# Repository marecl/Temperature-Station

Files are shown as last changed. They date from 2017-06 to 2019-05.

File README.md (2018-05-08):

# Temperature Station  
## I made this project for my father who needed to log activity of central heater  

Please use PCF8563_JSON version.  
I2C expander is ATmega board which will extend amount of sensors that can be connected (WIP).  

If there is Error[500] use another browser (8563 donsent work with Edge but DS32321 does idk why)  
	
		!!!TODO!!!  

	Main sketch:  
		1. Add SSL support (including login page)  
		2. WWW based updater  
		3. Automatic daylight saving  
		4. Encrypt WiFi password   
		5. Set date and time on the webpage  
		6. Save each file as JSON and show as CSV  
		7. SettingsGenerator for everything but sensors

	Czas.h library:  
		1. Return actual date and time as epoch  

	Hardware:   
		1. Make full-SMD version (without NodeMCU, just ESP-12E)

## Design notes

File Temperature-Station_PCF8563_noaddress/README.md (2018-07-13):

# This version is getting all updates  

It's using single JSON (saved as text) file to store all settings.  

Warning: This is still under development.  
You will need to use LwIP 1.4 Higher Bandwidth to compile due to UDP problems.  
  
Features:  
	1. Single configuration file  
	2. (quite) Easy configuration 
	3. Stable

	SDfiles:  
		Copy index.htm to the root of SDcard.  
		
	SETTINGS.TXT:  
		*To Do*  
	
# Warning on first run! (workaround)   
If You need to get sensor addresses and You are generating settings for the first time:  
		1. Asked for name and address enter whatever you want    
		(write 000,000,000,000,000,000,000,000)
		2. Enter \quit.
		3. Configure network
			3.1. IP address will be saved to settings file  
		4. Connect to Your station [ip]/sensors   
		5. Remove 000,000(and so on) sensor and name sensors shown in table.  
		Checkbox checked - this sensor's name will be removed.  

SettingsGenerator has got validation mechanisms. They're working for me.  
When invalid address (sensor or IP) is entered it will ask you to write it again. Simple.  

Order of logged temperatures is just as order in file.  
If you change this file remember to rename your current log file.  
For logging changes will be applied immediately, but header will remain the same until new file is generated.

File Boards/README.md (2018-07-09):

Use legacy SDcard symbol from KiCad.
SDCARD.kicad_mod is footprint for PCB.

Created using KiCAD.

Mainboard_1.1 - early version. Obsolete.
Mainboard_2.0 - prototype. Never created.
Mainboard_3.0 - last version. Working.
RJ45_Breakout - early version of Muxtemp. Obsolete but working with Mainboard_3.0
Mainboard_Final - Muxtemp integrated into mainboard. To be tested.
Muxtemp - Muxtemp board. To be tested (probably will not due to limited resources)

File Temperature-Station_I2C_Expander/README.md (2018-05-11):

I2C expansion board for main devices.  

To add more devices change N_PORTS and fill _pins array with pins you'd like to use.

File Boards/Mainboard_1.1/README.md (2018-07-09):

First version.
Single sided.
Requires retracing some SD lines which were connected to GPIO9&10.
No i2c breakout.

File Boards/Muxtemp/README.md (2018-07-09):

Muxtemp board.

Default address is 0x10. If you don't like it - change it in sketch

!Lock - device is processing data (low state) or it's available (high)
1wire (jumpers closed) - master device will maintain 1wire circuit (Dosen't show specific port used)
1wire (jumpers open) - Muxtemp will maintain 1wire circuit like local sensors
SDA/SCL - I2C
3V3 - fused in case of short
3V3_L - Logic 3V3 (unfused)

Power supply header is used for external power regulator.

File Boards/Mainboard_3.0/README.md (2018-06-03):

Current version.
Dosent use NodeMCU (which was hard to set due to different board sizes and pins).
Two layers.
Prepared for external I2C devices (like more sensors or controllers).
Made to be compatible with ESP-12 breakout board.
Tested, 100% working.

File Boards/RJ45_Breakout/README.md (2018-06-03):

Breakout board with RJ45 sockets to connect various types of sensors.

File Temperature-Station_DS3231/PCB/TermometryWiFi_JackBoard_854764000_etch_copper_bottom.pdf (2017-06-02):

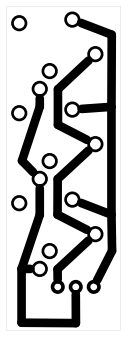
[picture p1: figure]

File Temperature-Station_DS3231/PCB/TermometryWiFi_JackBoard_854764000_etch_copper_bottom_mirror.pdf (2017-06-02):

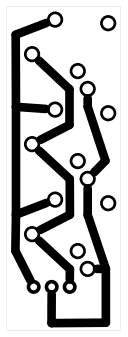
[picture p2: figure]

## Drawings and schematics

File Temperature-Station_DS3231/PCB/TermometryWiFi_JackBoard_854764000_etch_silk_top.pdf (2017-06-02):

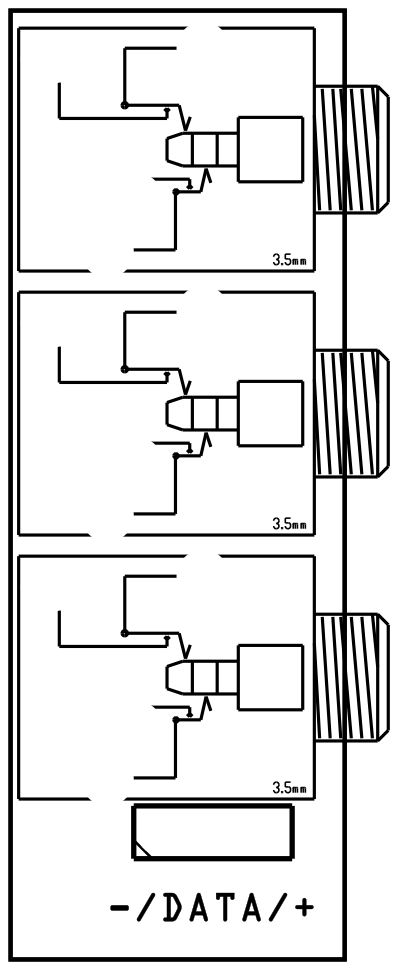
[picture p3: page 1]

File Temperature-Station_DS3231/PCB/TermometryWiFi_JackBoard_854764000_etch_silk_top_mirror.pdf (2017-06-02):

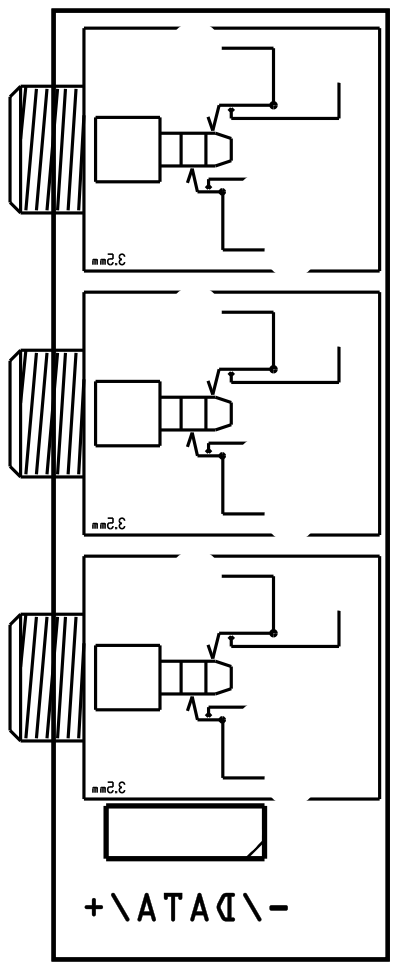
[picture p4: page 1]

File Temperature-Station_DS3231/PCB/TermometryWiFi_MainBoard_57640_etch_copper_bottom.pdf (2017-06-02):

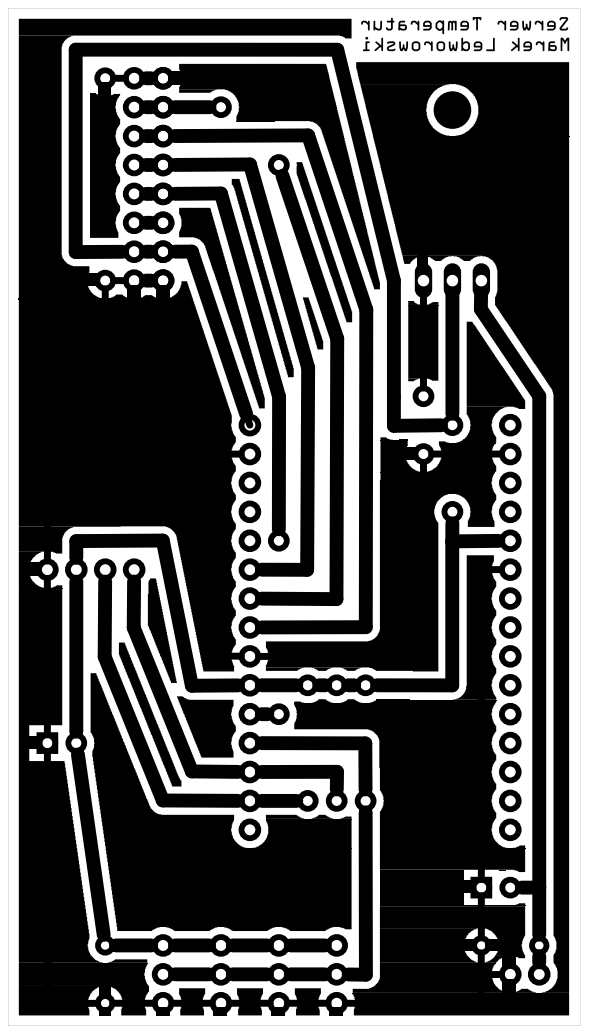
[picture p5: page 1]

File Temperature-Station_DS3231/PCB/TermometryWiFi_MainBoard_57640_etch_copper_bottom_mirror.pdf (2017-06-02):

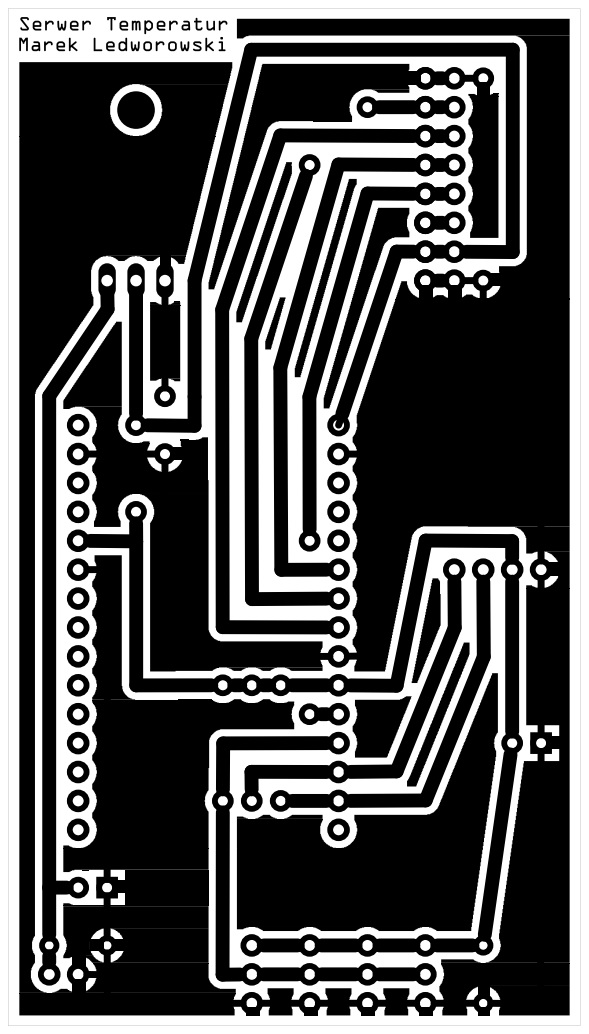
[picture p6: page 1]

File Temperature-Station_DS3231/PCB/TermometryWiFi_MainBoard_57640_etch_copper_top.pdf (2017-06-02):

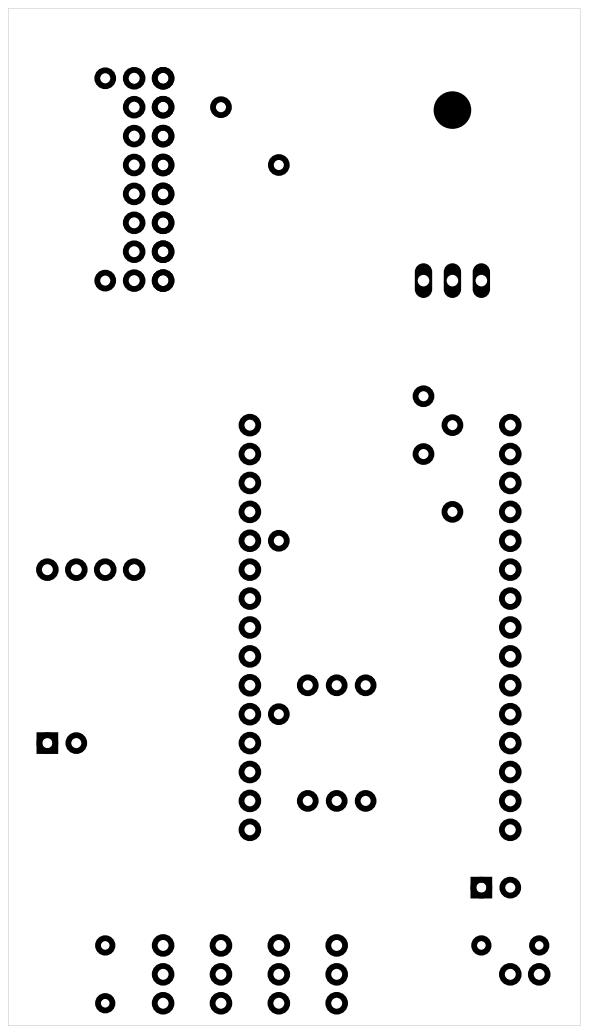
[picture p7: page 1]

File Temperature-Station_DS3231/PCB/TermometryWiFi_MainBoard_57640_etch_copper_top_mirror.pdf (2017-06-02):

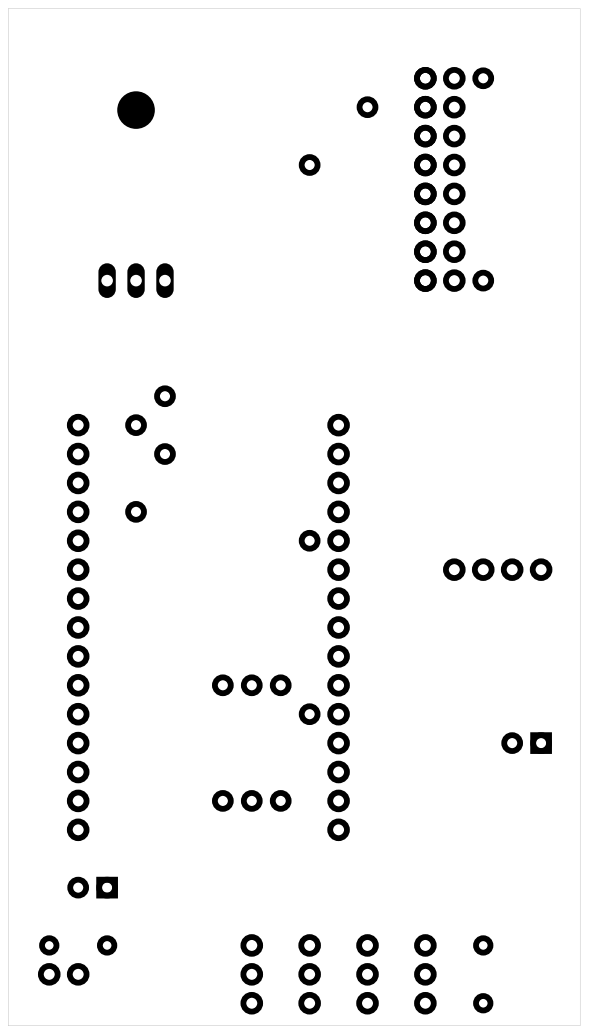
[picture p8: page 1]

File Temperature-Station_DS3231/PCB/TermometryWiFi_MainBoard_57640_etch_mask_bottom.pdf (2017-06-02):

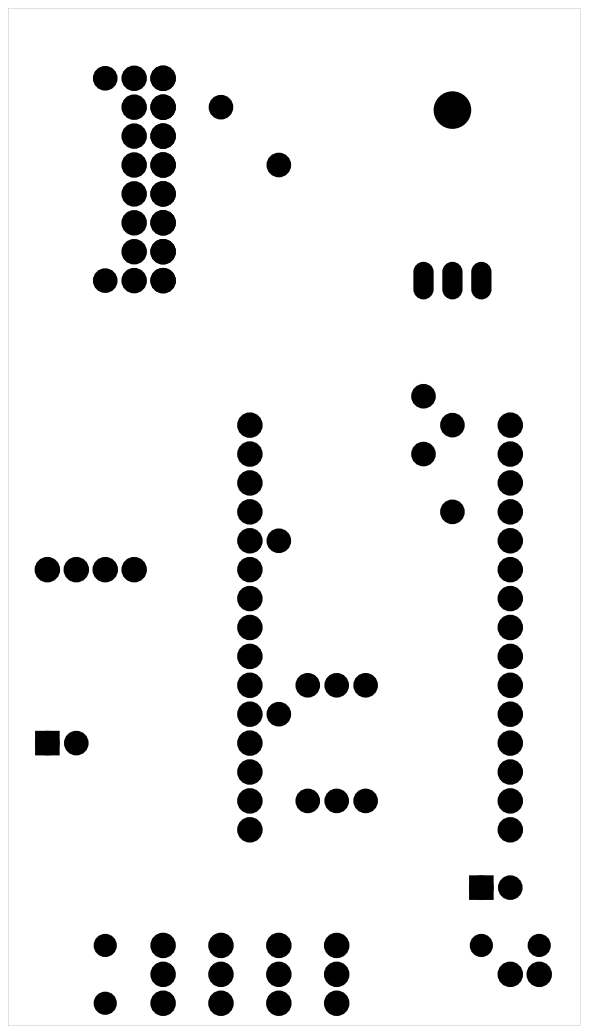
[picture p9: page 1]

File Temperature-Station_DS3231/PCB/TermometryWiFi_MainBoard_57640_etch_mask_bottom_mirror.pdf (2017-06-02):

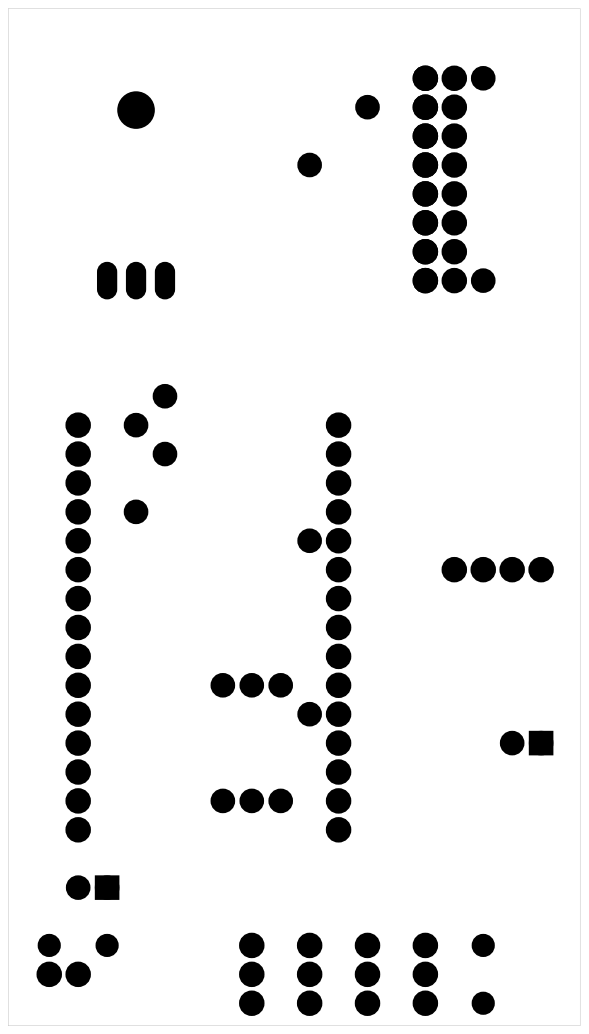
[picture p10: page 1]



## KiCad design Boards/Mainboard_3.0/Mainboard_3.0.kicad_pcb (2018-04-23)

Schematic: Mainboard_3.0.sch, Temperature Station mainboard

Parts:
BT1: Battery_Cell; BatteryHolder_Keystone_1058_1x2032
C1, C2, C3, C6, C7: 100nF; C_1206_3216Metric
C4, C5: 10uF; CP_EIA-6032-28_Kemet-C
D1, D2, D3: 1N4007; D_SMA
D4, D5: 1N4148; D_MiniMELF
J1: Breakout_Left; PinHeader_1x11_P2.54mm_Vertical
J2: Socket_Left; PinSocket_1x11_P2.54mm_Vertical_SMD_Pin1Left
J3: Jack-DC; BarrelJack_CUI_PJ-036AH-SMT_Horizontal
J4: Breakout_Right; PinHeader_1x11_P2.54mm_Vertical
J5: Socket_Right; PinSocket_1x11_P2.54mm_Vertical_SMD_Pin1Right
J6: 1-Wire; PinSocket_1x03_P2.54mm_Vertical_SMD_Pin1Left
J7: sensor_internal; PinSocket_1x03_P2.54mm_Vertical_SMD_Pin1Left
J8: Prog; PinHeader_1x05_P2.54mm_Horizontal
J9: SD_Card; SD_Card_Receptacle
J10: I2C Breakout; PinSocket_1x03_P2.54mm_Vertical_SMD_Pin1Left
Q1, Q2: S8050; TO-92
R1, R2, R3, R4, R5, R6, R7, R15: 4k7; R_1206_3216Metric
R8, R9, R10, R11, R12, R13, R14: 10k; R_1206_3216Metric
RJ1, RJ2, RJ3: 0; R_1206_3216Metric
U1: ESP-12E
U2: LM1117-3.3; SOT-223-3_TabPin2
U3: PCF8563T; SOIC-8_3.9x4.9mm_P1.27mm
Y1: 32,768kHz; Crystal_C26-LF_D2.1mm_L6.5mm_Horizontal_1EP_style1

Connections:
3v3: C2.1, C5.1, C6.1, C7.1, D3.2, D5.2, J2.8, J6.1, J7.1, J9.4, R2.1, R3.1, R4.1, R5.1, R6.1, R8.1, R9.1, R10.1, R11.1, R14.1, U2.2 (VO)
ADC: J2.2, J9.10, R14.2, R15.1
GND: BT1.2, C1.2, C2.2, C3.2, C4.2, C5.2, C6.2, C7.2, D1.2, J3.2, J3.3, J5.8, J6.3, J7.3, J8.5, J9.3, J9.6, J9.12, J9.13, J10.1, R1.1, R7.1, R15.2, U2.1 (GND), U3.4
GPIO0: J5.5, Q2.3, R5.2
GPIO2: J5.6, J6.2, J7.2, R6.2
GPIO4: J5.4, J10.3, R4.2, U3.6
GPIO5: J5.3, J10.2, R3.2, U3.5
GPIO12: J2.6, R8.2, RJ3.2
GPIO13: J2.7, J9.2, R10.2
GPIO14: J2.5, R9.2, RJ1.2
GPIO16: J2.4, J9.1, R11.2
unnamed: BT1.1, D4.2
unnamed: C3.1, C4.1, D2.1, D3.1, U2.3 (VI)
unnamed: D1.1, D2.2, J3.1
unnamed: D4.1, D5.1, U3.8
unnamed: J1.1, U1.11
unnamed: J1.2, U1.10
unnamed: J1.3, U1.9
unnamed: J1.4, U1.8
unnamed: J1.5, U1.7
unnamed: J1.6, U1.6
unnamed: J1.7, U1.5
unnamed: J1.8, U1.4
unnamed: J1.9, U1.3
unnamed: J1.10, U1.2
unnamed: J1.11, U1.1
unnamed: J2.3, R2.2
unnamed: J4.1, U1.12
unnamed: J4.2, U1.13
unnamed: J4.3, U1.14
unnamed: J4.4, U1.15
unnamed: J4.5, U1.16
unnamed: J4.6, U1.17
unnamed: J4.7, U1.18
unnamed: J4.8, U1.19
unnamed: J4.9, U1.20
unnamed: J4.10, U1.21
unnamed: J4.11, U1.22
unnamed: J5.7, R7.2
unnamed: J8.1, Q1.1, R13.2
unnamed: J8.2, Q2.1, R12.2
unnamed: J9.5, RJ1.1
unnamed: J9.7, RJ3.1
unnamed: Q1.2, R12.1
unnamed: Q1.3, RJ2.1
unnamed: Q2.2, R13.1
unnamed: U3.1, Y1.1
unnamed: U3.2, Y1.2
RST: C1.1, J2.1, R1.2, RJ2.2
RX: J5.2, J8.3
TX: J5.1, J8.4

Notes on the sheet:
ADC - SD_D GPIO12 - MISO GPIO13 - MOSI GPIO14 - SCK GPIO16 - CS GPIO2 - 1wire GPIO4 - SCL GPIO5 - SDA
GND TX -> RX RX -> TX RTS DTR

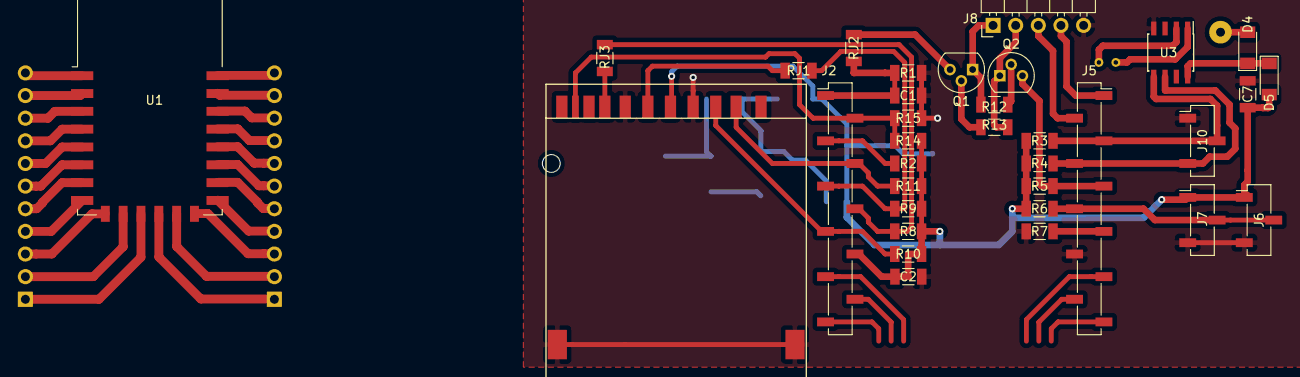
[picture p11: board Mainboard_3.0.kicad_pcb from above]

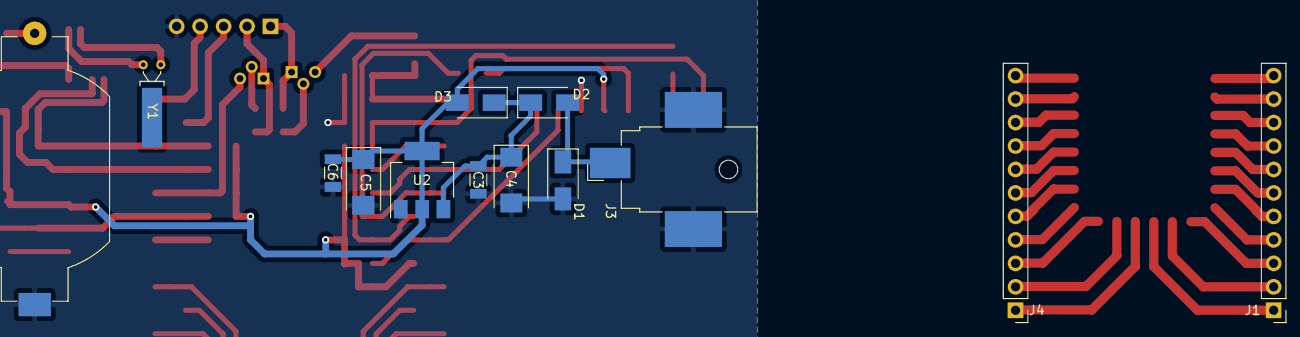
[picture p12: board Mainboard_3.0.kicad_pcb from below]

Board: 2 copper layers, 47 parts (13 on the bottom side), 51 nets.

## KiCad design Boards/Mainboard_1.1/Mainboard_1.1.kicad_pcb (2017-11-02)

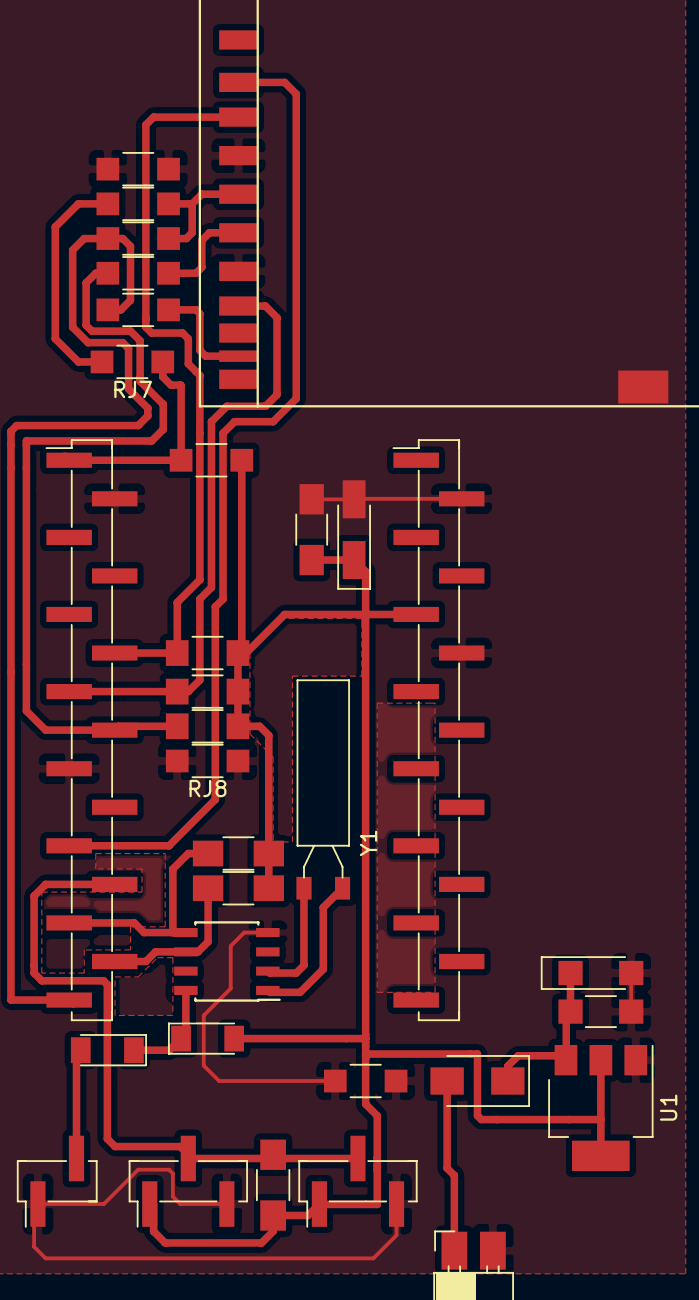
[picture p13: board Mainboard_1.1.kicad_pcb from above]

Board: 2 copper layers, 32 parts (0 on the bottom side), 18 nets.

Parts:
C1, C3: 10nF; C_1206_HandSoldering
C2, C4: 10uF; CP_Tantalum_Case-A_EIA-3216-18_Hand
D1, D3: 1N4148; D_MiniMELF
D2: 1N4007; D_SMA
J1, J5: CONN_01X03; Pin_Header_Straight_1x03_Pitch2.54mm_SMD_Pin1Left
J2, J3: CONN_01X15; Pin_Header_Straight_1x15_Pitch2.54mm_SMD_Pin1Left
J4: SD_Card; SDCARD-STANDARD
J6: CONN_01X02; Pin_Header_Straight_1x02_Pitch2.54mm_SMD_Pin1Left
J7: CONN_01X02; Socket_Strip_Angled_1x02_Pitch2.54mm
R1, R2, R3, R4: 10k; R_1206_HandSoldering
R5, R6, R7: 4k7; R_1206_HandSoldering
RJ1, RJ2, RJ3, RJ4, RJ5, RJ6, RJ7, RJ8: 0; R_1206_HandSoldering
U1: LM1117-3.3; SOT-223-3Lead_TabPin2
U2: PCF8563; SOIC-8_3.9x4.9mm_Pitch1.27mm
Y1: Crystal; Crystal_AT310_d3.0mm_l10.0mm_Horizontal

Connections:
1wire: J1.2, J2.12, J5.2, R5.2
3V3: C3.1, C4.1, D1.2, J1.1, J2.1, J3.5, J4.4, J5.1, R1.1, R2.1, R3.1, R4.1, R5.1, R6.1, R7.1, RJ2.1, RJ2.2, RJ3.1, RJ3.2, RJ7.1, RJ7.2, U1.2
CS: J2.11, J4.1
GND: C1.2, C2.2, C3.2, C4.2, J1.3, J2.2, J2.9, J3.2, J3.6, J4.3, J4.6, J4.12, J5.3, J6.1, J7.2, RJ4.1, RJ4.2, RJ6.1, RJ6.2, RJ8.1, RJ8.2, U1.1, U2.4
MISO: J2.7, J4.7, R2.2
MOSI: J2.6, J4.2, R1.2
unnamed: C1.1, C2.1, D2.1, U1.3
unnamed: D1.1, D3.1, U2.8
unnamed: D2.2, J7.1
unnamed: D3.2, J6.2
unnamed: J2.8, R3.2, RJ1.1
unnamed: J4.10, RJ5.2
unnamed: U2.1, Y1.1
unnamed: U2.2, Y1.2
SCK: J4.5, RJ1.2
SCL: J2.14, R7.2, U2.6
SDA: J2.13, R6.2, U2.5
SD_D: J2.15, R4.2, RJ5.1

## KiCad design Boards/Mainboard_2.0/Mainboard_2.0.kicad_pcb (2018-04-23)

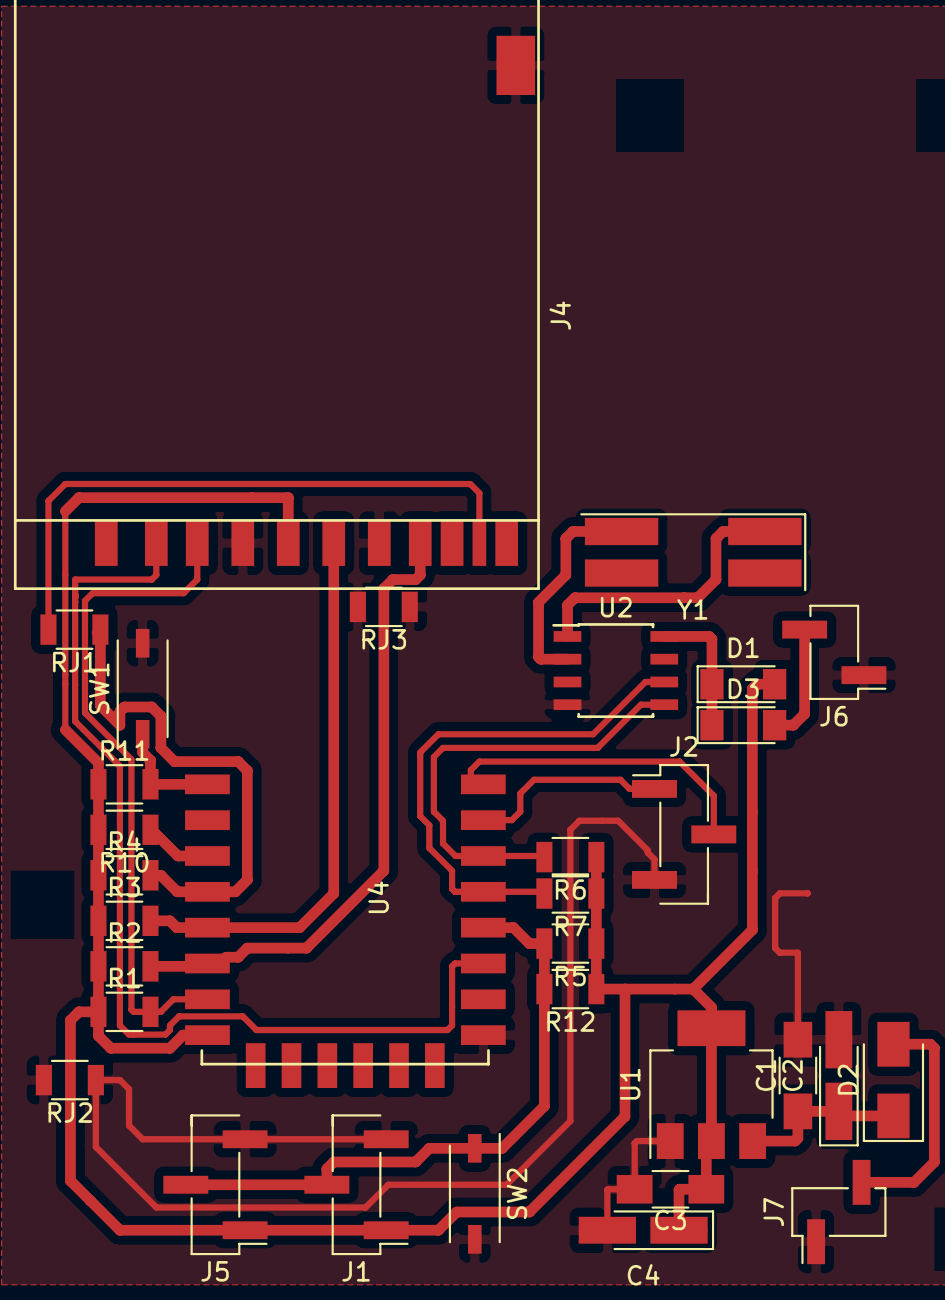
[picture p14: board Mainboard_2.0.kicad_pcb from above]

Board: 2 copper layers, 32 parts (0 on the bottom side), 21 nets.

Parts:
C1, C3: 10nF; C_1206_HandSoldering
C2, C4: 10uF; CP_Tantalum_Case-A_EIA-3216-18_Hand
D1, D3: 1N4148; D_MiniMELF
D2: 1N4007; D_SMA
J1, J2, J5: CONN_01X03; Pin_Header_Straight_1x03_Pitch2.54mm_SMD_Pin1Left
J4: SD_Card; SDCARD-STANDARD
J6, J7: CONN_01X02; Pin_Header_Straight_1x02_Pitch2.54mm_SMD_Pin1Left
R1, R2, R3, R4: 10k; R_1206
R5, R6, R7: 4k7; R_1206
R10, R11, R12: 1k; R_1206
RJ1, RJ2, RJ3: 0; R_1206
SW1: RESET; SW_DIP_x1_W5.08mm_Slide_Copal_CHS-A
SW2: FLASH; SW_DIP_x1_W5.08mm_Slide_Copal_CHS-A
U1: LM1117-3.3; SOT-223-3Lead_TabPin2
U2: PCF8563; SOIC-8_3.9x4.9mm_Pitch1.27mm
U4: ESP-12E; ESP-12E_SMD
Y1: Crystal; Crystal_SMD_SeikoEpson_MC406-4pin_9.6x4.1mm

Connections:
1wire: J1.2, J5.2, R5.2, R12.2, SW2.1, U4.12
3V3: C3.1, C4.1, D1.2, J1.1, J4.4, J5.1, R1.1, R2.1, R3.1, R4.1, R5.1, R6.1, R7.1, R10.2, R11.1, R12.1, U1.2, U4.8
CS: J4.1, U4.11
GND: C1.2, C2.2, C3.2, C4.2, J1.3, J2.3, J4.3, J4.6, J4.12, J5.3, J6.1, J7.1, RJ2.1, RJ2.2, RJ3.1, RJ3.2, SW1.2, SW2.2, U1.1, U2.4, U4.9
GPIO4: R7.2, U2.6, U4.13
GPIO5: R6.2, U2.5, U4.14
GPIO12: J4.7, R2.2, U4.6
GPIO13: J4.2, R1.2, U4.7
GPIO14: J4.5, R3.2, U4.5
unnamed: C1.1, C2.1, D2.1, U1.3
unnamed: D1.1, D3.1, U2.8
unnamed: D2.2, J7.2
unnamed: D3.2, J6.2
unnamed: J4.10, RJ1.2
unnamed: R10.1, U4.3
unnamed: U2.1, Y1.1
unnamed: U2.2, Y1.2
RESET: R11.2, SW1.1, U4.1
Rx: J2.1, U4.15
SD_D: R4.2, RJ1.1, U4.4
Tx: J2.2, U4.16

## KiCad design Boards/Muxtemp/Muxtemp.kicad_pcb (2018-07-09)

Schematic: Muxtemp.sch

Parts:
F1: 500mA; Fuse_1206_3216Metric
J1, J2, J3, J4, J5, J6, J7, J8: MHRJJ66NFRA; Manufacturer_Part_Number MHRJJ66NFRA
J9: ATmega Prog; PinHeader_1x04_P2.54mm_Vertical
J10: Conn; PinHeader_1x07_P2.54mm_Horizontal
J11: Power Supply; PinHeader_1x04_P2.54mm_Vertical
JP1, JP2, JP3, JP4, JP5, JP6, JP7, JP8, JP9: 1wireBypass; R_0612_1632Metric
R1, R2, R3, R4, R5, R6, R7, R8: 4k7; R_1206_3216Metric
R9, R10, R11, R12, R13, R14, R15, R16: 33k; R_1206_3216Metric
R17, R18: 100k; R_1206_3216Metric
R19: 10k; R_Axial_DIN0207_L6.3mm_D2.5mm_P10.16mm_Horizontal
U1: ATmega328P-AU; TQFP-32_7x7mm_P0.8mm

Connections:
1wire: J10.4, JP1.2, JP2.2, JP3.2, JP4.2, JP5.2, JP6.2, JP7.2, JP8.2, R17.2, U1.25 (PC2)
3V3: F1.1, J1.6, J2.6, J3.6, J4.6, J5.6, J6.6, J7.6, J8.6, R1.1, R2.1, R3.1, R4.1, R5.1, R6.1, R7.1, R8.1
3V3_L: F1.2, J10.6, J11.1, R19.1, U1.4 (VCC), U1.6 (VCC), U1.18 (AVCC)
GND: J1.2, J1.3, J2.2, J2.3, J3.2, J3.3, J4.2, J4.3, J5.2, J5.3, J6.2, J6.3, J7.2, J7.3, J8.2, J8.3, J9.1, J10.5, J11.2, JP9.2, R9.1, R10.1, R11.1, R12.1, R13.1, R14.1, R15.1, R16.1, R17.1, U1.3 (GND), U1.5 (GND), U1.21 (GND)
Lock: J10.3, U1.26 (PC3)
unnamed: J1.4, JP1.1
unnamed: J1.5, R1.2
unnamed: J2.4, JP2.1
unnamed: J2.5, R2.2
unnamed: J3.4, JP3.1
unnamed: J3.5, R3.2
unnamed: J4.4, JP4.1
unnamed: J4.5, R4.2
unnamed: J5.4, JP5.1
unnamed: J5.5, R5.2
unnamed: J6.4, JP6.1
unnamed: J6.5, R6.2
unnamed: J7.4, JP7.1
unnamed: J7.5, R7.2
unnamed: J8.4, JP8.1
unnamed: J8.5, R8.2
unnamed: J11.4, R18.1
unnamed: JP9.1, U1.24 (PC1)
unnamed: R19.2, U1.29 (~RESET~/PC6)
SCL: J10.1, U1.28 (PC5)
SDA: J10.2, U1.27 (PC4)
Vin: J10.7, J11.3, R18.2
dht_0: J1.1, J9.4, R9.2, U1.16 (PB4)
dht_1: J2.1, J9.3, R10.2, U1.15 (PB3)
dht_2: J3.1, J9.2, R11.2, U1.14 (PB2)
dht_3: J4.1, R12.2, U1.13 (PB1)
dht_4: J5.1, R13.2, U1.12 (PB0)
dht_5: J6.1, R14.2, U1.11 (PD7)
dht_6: J7.1, R15.2, U1.10 (PD6)
dht_7: J8.1, R16.2, U1.9 (PD5)

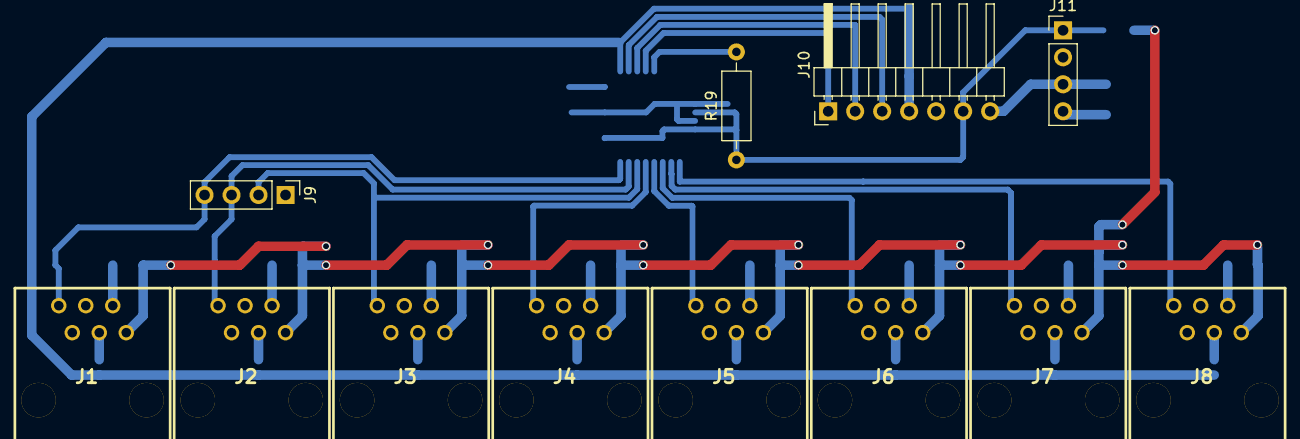
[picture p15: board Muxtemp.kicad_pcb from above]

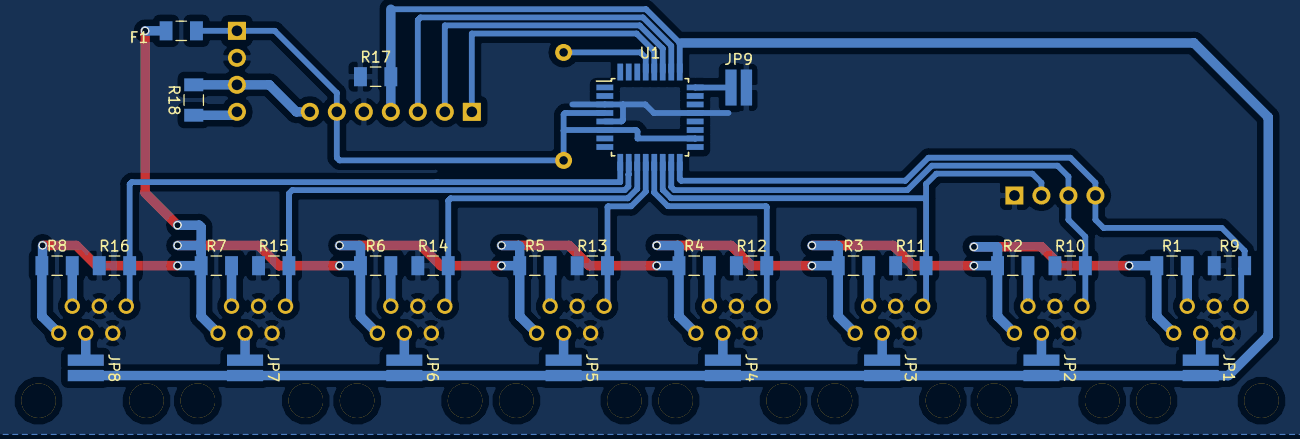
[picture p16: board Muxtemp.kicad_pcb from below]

Board: 2 copper layers, 41 parts (29 on the bottom side), 35 nets.

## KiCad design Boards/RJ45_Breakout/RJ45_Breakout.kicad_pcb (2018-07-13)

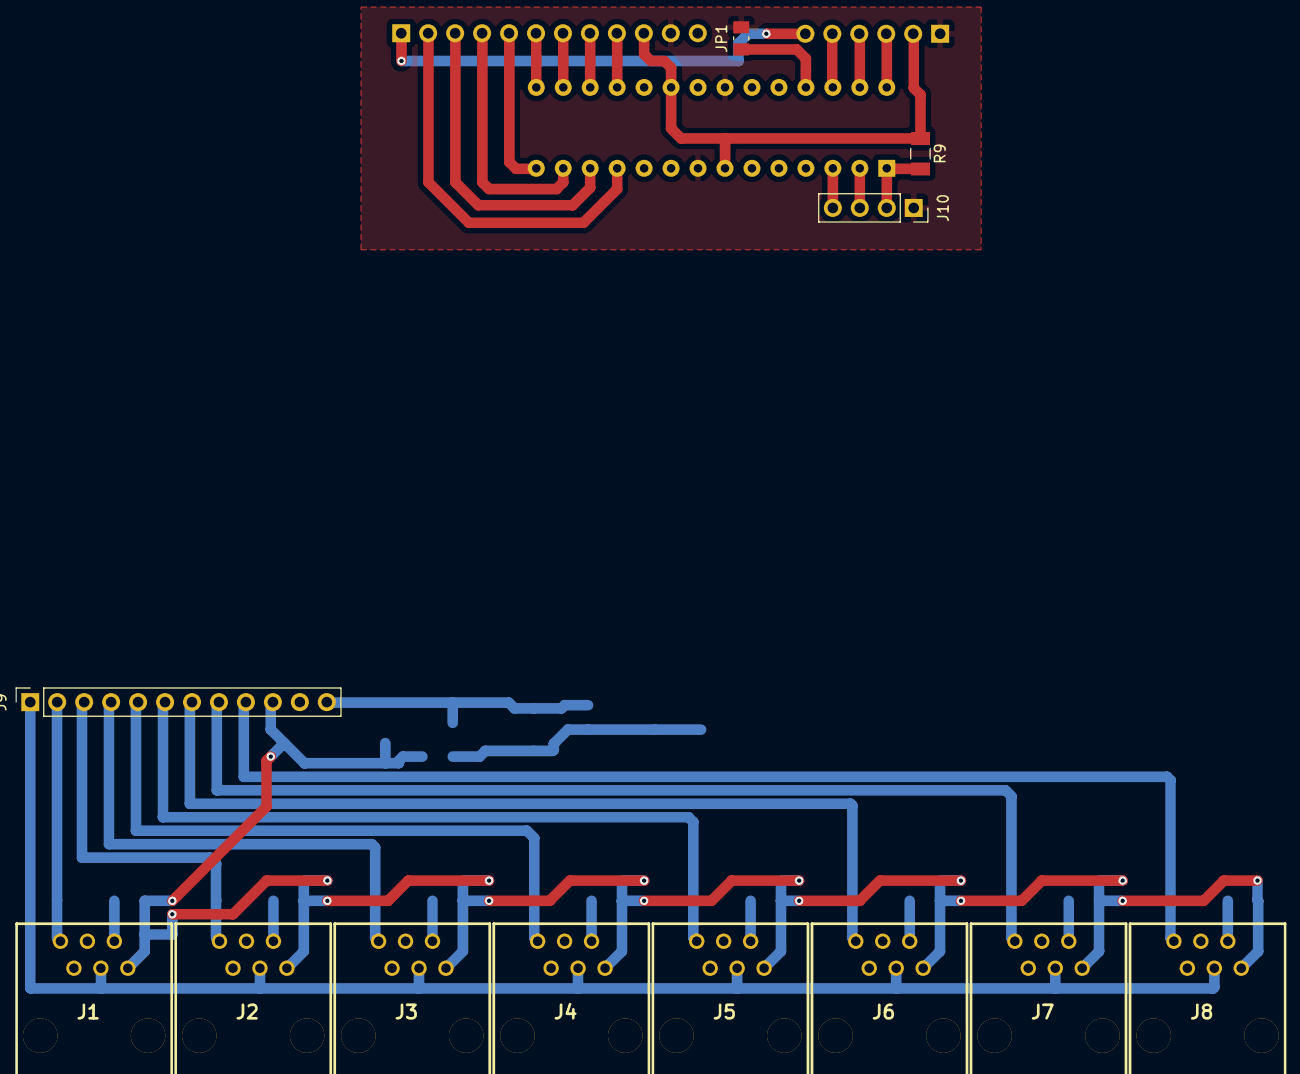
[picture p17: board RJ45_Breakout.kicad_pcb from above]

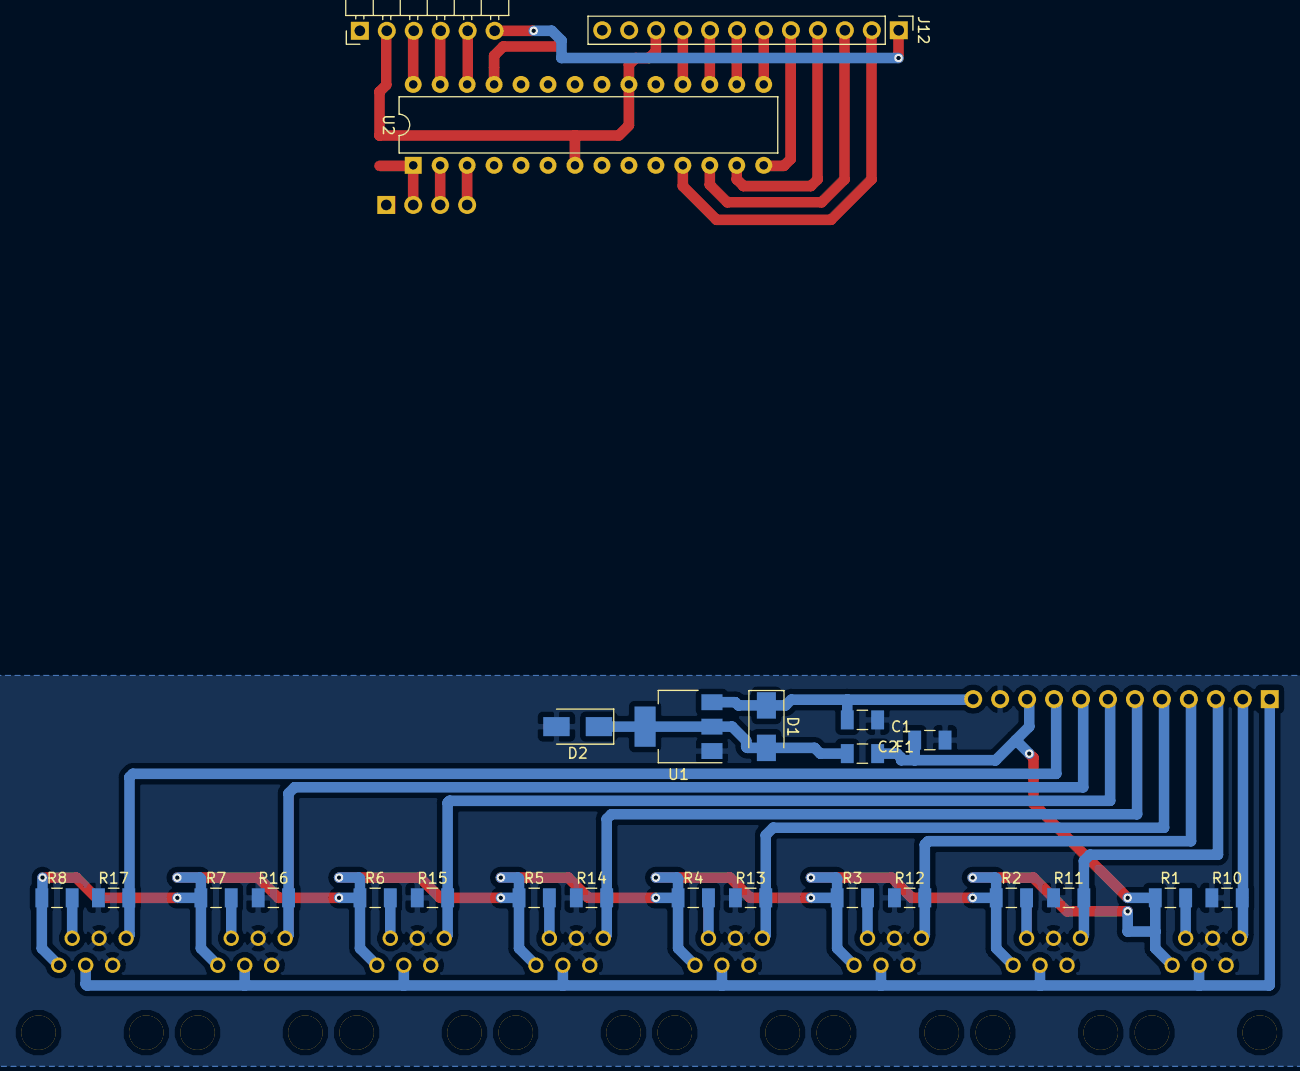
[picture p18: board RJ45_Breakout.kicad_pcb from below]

Board: 2 copper layers, 37 parts (25 on the bottom side), 28 nets.

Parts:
C1, C2: 100nF; C_1206_3216Metric
D1, D2: 1N4007; D_SMA
F1: 500mA; Fuse_1206_3216Metric
J1, J2, J3, J4, J5, J6, J7, J8: MHRJJ66NFRA
J9: Conn_01x12; PinSocket_1x12_P2.54mm_Vertical
J10: Prog; PinSocket_1x04_P2.54mm_Vertical
J11: Out; PinHeader_1x06_P2.54mm_Horizontal
J12: Flex; PinHeader_1x12_P2.54mm_Vertical
JP1: bypass1Wire; R_0805_2012Metric_Pad1.15x1.50mm_HandSolder
R1, R2, R3, R4, R5, R6, R7, R8: 4k7; R_1206_3216Metric
R9: 10k; R_1206_3216Metric
R10, R11, R12, R13, R14, R15, R16, R17: 33k; R_1206_3216Metric
U1: LM1117-3.3; SOT-223-3_TabPin2
U2: ATmega328-PU; DIP-28_W7.62mm

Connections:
1wire: J1.4, J2.4, J3.4, J4.4, J5.4, J6.4, J7.4, J8.4, J9.1, J11.6, J12.1
3V3: C2.1, F1.1, J1.6, J2.6, J3.6, J4.6, J5.6, J6.6, J7.6, J8.6, J9.10, J11.2, J12.10, R1.1, R2.1, R3.1, R4.1, R5.1, R6.1, R7.1, R8.1, R9.1, U2.7, U2.20
!Lock: J11.5, U2.26
GND: C1.2, C2.2, D2.2, J1.2, J1.3, J2.2, J2.3, J3.2, J3.3, J4.2, J4.3, J5.2, J5.3, J6.2, J6.3, J7.2, J7.3, J8.2, J8.3, J9.11, J10.1, J11.1, J12.11, JP1.2, R10.1, R11.1, R12.1, R13.1, R14.1, R15.1, R16.1, R17.1, U1.1, U2.8, U2.22
unnamed: D1.2, D2.1, F1.2, U1.2
unnamed: J1.5, R1.2
unnamed: J2.5, R2.2
unnamed: J3.5, R3.2
unnamed: J4.5, R4.2
unnamed: J5.5, R5.2
unnamed: J6.5, R6.2
unnamed: J7.5, R7.2
unnamed: J8.5, R8.2
unnamed: J10.2, R9.2, U2.1
unnamed: J10.3, U2.2
unnamed: J10.4, U2.3
unnamed: JP1.1, U2.25
SCL: J11.3, U2.28
SDA: J11.4, U2.27
Vin: C1.1, D1.1, J9.12, J12.12, U1.3
dht_0: J1.1, J9.2, J12.2, R10.2, U2.11
dht_1: J2.1, J9.3, J12.3, R11.2, U2.12
dht_2: J3.1, J9.4, J12.4, R12.2, U2.13
dht_3: J4.1, J9.5, J12.5, R13.2, U2.14
dht_4: J5.1, J9.6, J12.6, R14.2, U2.15
dht_5: J6.1, J9.7, J12.7, R15.2, U2.16
dht_6: J7.1, J9.8, J12.8, R16.2, U2.17
dht_7: J8.1, J9.9, J12.9, R17.2, U2.18

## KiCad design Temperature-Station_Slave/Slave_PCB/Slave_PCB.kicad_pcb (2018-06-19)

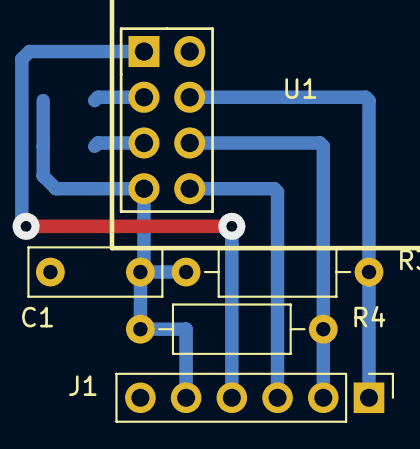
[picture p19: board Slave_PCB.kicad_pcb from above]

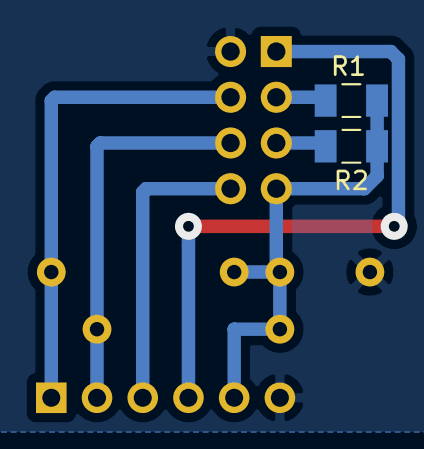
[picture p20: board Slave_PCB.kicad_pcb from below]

Board: 2 copper layers, 7 parts (2 on the bottom side), 8 nets.

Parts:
C1: 100nF; C_Rect_L7.2mm_W2.5mm_P5.00mm_FKS2_FKP2_MKS2_MKP2
J1: COM; PinHeader_1x06_P2.54mm_Vertical
R1, R2: 10k; R_1206_3216Metric
R3, R4: 4k7; R_Axial_DIN0207_L6.3mm_D2.5mm_P10.16mm_Horizontal
U1: ESP-01v090; ESP-01

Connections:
3V3: C1.1, J1.5, R1.1, R2.1, R3.2, R4.2, U1.7
GND: C1.2, J1.6, U1.2
unnamed: R1.2, U1.3
unnamed: R2.2, U1.5
SCL: J1.2, R4.1, U1.6
SDA: J1.1, R3.1, U1.4
hRX: J1.4, U1.1
hTX: J1.3, U1.8

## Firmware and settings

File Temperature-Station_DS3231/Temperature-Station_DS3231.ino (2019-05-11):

#include <ArduinoJson.h>
#include <ArduinoOTA.h>
#include <DallasTemperature.h>
#include <ESP8266HTTPUpdateServer.h>
#include <ESP8266WebServerSecure.h>
#include <ESP8266WiFi.h>
#include <OneWire.h>
#include <RtcDS3231.h>
#include <settingsManager.h>
#include <SD.h>
#include <SPI.h>
#include <Wire.h>
#include <WiFiUdp.h>
#include "CommonUtils.hpp"
#include "SensorsPageHandler.hpp"
#include "SensorsEditPageHandler.hpp"
#include "TimePageHandler.hpp"
#include "LoginPageHandler.hpp"

/*
   przy niewaznym ciasteczku przekierowac na /login
   naprawic /login
   Dostep do plikow przez strona/file=/[sciezka]
   wywalic strings.cpp
*/

#define FS_NO_GLOBALS
#include "FS.h"

/* Pin definitions */
#define SD_D D0     //GPIO16
#define SDA D1      //GPIO5
#define SCL D2      //GPIO4
#define OW_PORT D3  //GPIO0
#define SD_CS D4    //GPIO2

/* Good when trying different configurations */
#define SETTINGS_FILE "/SET.TXT" //SPIFFS
#define SENSORS_FILE "/DATA/SENSORS.TXT" //SD

/* Webpage */
extern char settings_htm[];

ESP8266WebServer server(80);
//ESP8266WebServerSecure server(443);
ESP8266HTTPUpdateServer updServer;

OneWire oneWire(OW_PORT);
DallasTemperature sensors(&oneWire);

RtcDS3231<TwoWire> zegar(Wire);
RtcDateTime teraz;

settingsManager settings(SETTINGS_FILE);

settingsManager* CommonUtils::setptr = &settings;
uint32_t CommonUtils::globalTimer = 0;

void setup() {
  SPIFFS.begin();
  WiFi.disconnect();
  WiFi.persistent(false);
  Serial.begin(115200);
  Serial.setDebugOutput(false);
  Serial.println(F("\r\n\r\nBooting..."));
  pinMode(SD_D, INPUT);

  if (!digitalRead(SD_D)) {
    if (SD.begin(SD_CS)) Serial.println(F("SD Card initialized"));
    else Serial.println(F("SD Card detected but cannot be initialized!"));
  } else Serial.println(F("No card inserted"));

#ifdef DEBUG_INSECURE
  settings.serialDebug(&Serial);
  //Use this section to overwrite settings while debugging
  settings.configSTA("", "");  // ssid and password
  settings.configAP("TemperatureStation");            // AP ssid
  settings.useDHCP(true);
  settings.name("TemperatureStation");                // Device name
  settings.ntpServer("tempus1.gum.gov.pl");           // NTP server (not pool)
  settings.configUser("admin", "admin");              // Login and password
  settings.timezone = 1;
  settings.useNTP = true;
  settings.readInterval = 10;                         // Read interval [min]
  settings.tokenLifespan = 600;                      // Cookie lifespan [s]
  settings.save();
  settings.printConfig();
#endif

  Serial.print(F("Loading..."));
  if (!settings.load()) { //Fill with default values
    Serial.println(F(" Fail"));
    settings.configUser("admin", "admin");
    settings.name(PSTR("TemperatureStation"));
    settings.configAP(("TemperatureStation" + (String)ESP.getChipId()).c_str(), "TemperatureStation");
  } else Serial.println(F("OK"));

  bool gotwifi = false;
  if (strcmp(settings.ssid(), "")) {
    Serial.print(F("Connecting to:\r\n\t"));
    Serial.print(settings.ssid());
    if (settings.beginSTA()) {
      Serial.print(F("\tSuccess \r\nIP Address:\t"));
      Serial.print(WiFi.localIP());
      gotwifi = true;
    } else {
      Serial.print(F("\tConnection failed"));
      gotwifi = false;
    }
    Serial.println();
  }

  if (!gotwifi) {
    Serial.print(F("Starting Access Point... "));
    Serial.println(settings.beginAP() ? F("Success") : F("Fail"));
    Serial.print(F("Connect to:\t"));
    Serial.println(settings.ssidAP());
  }

  sensors.begin();
  sensors.requestTemperatures();

  const char* headerkeys[] = {"Cookie"};
  uint16_t headerkeyssize = sizeof(headerkeys) / sizeof(char*);
  server.collectHeaders(headerkeys, headerkeyssize);
  //settings.configUpdateServer(&server, &updServer, "/update");
  //add SSL/BearSSL key
  server.addHandler(new LoginPageHandler("/login"));
  server.addHandler(new SensorsPageHandler("/sensors", &sensors, SENSORS_FILE));
  server.addHandler(new SensorsEditPageHandler("/editsaved", SENSORS_FILE));
  server.on("/settings", devconfig);
  //server.addHandler(new TimePageHandler("/time", &settings));
  server.on("/time", HTTP_POST, timeset);
  server.on("/logout", []() {
    server.sendHeader("Set-Cookie", settings.encryptKey(1));
    server.sendHeader("Location", "/login");
    server.sendHeader("Cache-Control", "no-cache");
    server.send(301);
  });
  server.onNotFound(handleNotFound);
  server.begin();
  settings.beginOTA();

  Serial.println(F("HTTP server:\tStarted"));

  if (!digitalRead(SDA))
    I2C_clearBus();

  Wire.begin(SDA, SCL);
  zegar.Begin();
  zegar.SetIsRunning(true);

  if (settings.useNTP) {
    teraz = zegar.GetDateTime();
    uint32_t newTime = updateNTP(settings.ntpServer());
    if ((newTime > 0 && (newTime - (uint32_t)teraz) > 59) || settings.lastUpdate == 0) {
      Serial.println(F("Adjusting time..."));
      Serial.println(PSTR("Before: ") + String(teraz));
      Serial.println(PSTR("Current: ") + String(newTime));
      zegar.SetIsRunning(false);
      zegar.SetDateTime(RtcDateTime(newTime));
      settings.lastUpdate = teraz;
      zegar.SetIsRunning(true);
    }
  }
  teraz = zegar.GetDateTime();
  char *date = new char[20];
  Serial.println(CommonUtils::printDateTime(date, &teraz));
  delete[] date;
  settings.save();

  CommonUtils::refreshSensors(&oneWire, SENSORS_FILE);

  DynamicJsonBuffer jsonBuffer(1000);
  File root = SD.open(SENSORS_FILE, FILE_READ);
  JsonArray& nSet = jsonBuffer.parseArray(root);
  root.close();

  Serial.println(F("\nLocal:"));
  uint8_t nSensor = nSet.size();
  for (uint8_t a = 0; a < nSensor; a++) {
    JsonArray& _e = nSet[a];
    Serial.print('\t' + String(a + 1) + "/" + String(nSensor) + ": ");
    Serial.print(_e[0].as<const char*>());
    if (CommonUtils::getTemp(&sensors, _e[1]) != -127)
      Serial.println(F(" Connected"));
    else Serial.println(F(" N/C"));
  }
}

void loop() {
  while (CommonUtils::globalTimer = zegar.GetDateTime(), \
         CommonUtils::globalTimer % (settings.readInterval * 60) != 0) {
    server.handleClient();
    ArduinoOTA.handle();
    yield();
  }

  if (!digitalRead(SD_D)) {
    sensors.requestTemperatures();
    teraz = zegar.GetDateTime();

    DynamicJsonBuffer jsonBuffer(1000);
    File root = SD.open(SENSORS_FILE , FILE_READ);
    JsonArray& nSet = jsonBuffer.parseArray(root);
    root.close();

    char* filename = new char[24];
    createFile(filename, 24, teraz);

    File dest = SD.open(filename, FILE_WRITE);

    char *date = new char[20];
    Serial.print(CommonUtils::printDateTime(date, &teraz));
    Serial.println(F("\tZapis"));

    dest.print(date);
    dest.print(F(";"));
    dest.print(settings.name());
    dest.print(F(":("));
    dest.flush();
    delete[] date;
    bool first = true;
    for (uint8_t c = 0; c < nSet.size(); c++) {
      JsonArray& _e = nSet[c];
      double tempRead = CommonUtils::getTemp(&sensors, _e[1]);
      if (tempRead == -127) continue;

      if (!first) dest.print(F(","));
      else first = false;
      dest.print(_e[0].as<const char*>());
      dest.print(F("="));
      dest.print(tempRead, 1);
      dest.flush();

    }
    dest.println(F(");"));
    dest.flush();
    dest.close();
    delete[] filename;
  } else {
    Serial.println(F("!!! NO SDCARD !!!"));
    while (digitalRead(SD_D)) {
      yield();
    }
    Serial.println(F("SD Card inserted. Rebooting..."));
    ESP.restart();
  }

  while (CommonUtils::globalTimer = zegar.GetDateTime(),
         CommonUtils::globalTimer % (settings.readInterval * 60) == 0) {
    server.handleClient();
    ArduinoOTA.handle();
    yield();
  }
}

uint32_t updateNTP(const char* ntpServerName) {
  WiFiUDP udp;
  IPAddress timeServerIP;
  udp.begin(2390);
  WiFi.hostByName(ntpServerName, timeServerIP);
  Serial.print(F("Time sync..."));

  byte packetBuffer[48];
  memset(packetBuffer, 0, 48);
  packetBuffer[0] = 0b11100011;
  packetBuffer[1] = 0;
  packetBuffer[2] = 6;
  packetBuffer[3] = 0xEC;
  packetBuffer[12] = 49;
  packetBuffer[13] = 0x4E;
  packetBuffer[14] = 49;
  packetBuffer[15] = 52;

  int cb = udp.parsePacket();

  uint8_t i = 0;
  while (!cb && i++ < 10) {
    udp.beginPacket(timeServerIP, 123);
    udp.write(packetBuffer, 48);
    udp.endPacket();
    udp.flush();
    delay(1000);
    cb = udp.parsePacket();
  }

  if (i < 10 && cb) {
    udp.read(packetBuffer, 48);
    unsigned long highWord = word(packetBuffer[40], packetBuffer[41]);
    unsigned long lowWord = word(packetBuffer[42], packetBuffer[43]);
    unsigned long secsSince1900 = highWord << 16 | lowWord;
    secsSince1900 -= 2208988800UL;
    secsSince1900 -= 946684800;
    secsSince1900 += settings.timezone * 3600;
    Serial.println(F(" OK"));
    return secsSince1900;
  }
  Serial.println(F(" Fail"));
  return false;
}

void devconfig() {
  if (!LoginPageHandler::verifyLogin(&server, &settings)) {
    LoginPageHandler::redirectToLogin(&server);
    return;
  }

  if (server.method() == HTTP_POST) {
    DynamicJsonBuffer output(JSON_OBJECT_SIZE(11));
    JsonObject& data = output.createObject();
    String resp;
    if (server.arg("a") == "l") {
      server.setContentLength(CONTENT_LENGTH_UNKNOWN);
      data["SN"] = settings.name();
      data["SS"] = settings.ssidAP();
      data["OS"] = settings.ssid();
      data["OI"] = settings.IPtoString(WiFi.localIP());
      data["OG"] = settings.IPtoString(WiFi.gatewayIP());
      data["OM"] = settings.IPtoString(WiFi.subnetMask());
      data["OD"] = settings.useDHCP();
      data["SL"] = settings.username();
      data["UN"] = settings.useNTP;
      data["NS"] = settings.ntpServer();
      data["TZ"] = settings.timezone;
      data.printTo(resp);
      server.send(200, F("application/json"), resp);
    } else if (server.arg("a") == "s") {
      if (server.hasArg("SS") && server.hasArg("SPA"))
        settings.configAP(server.arg("SS").c_str(),
                          server.arg("SPA").c_str());
      if (server.hasArg("OS") && server.hasArg("OP"))
        settings.configSTA(server.arg("OS").c_str(),
                           server.arg("OP").c_str());
      if (server.hasArg("OD"))
        settings.useDHCP(server.arg("OD")[0] == '1');
      if (server.hasArg("SN"))
        settings.name(server.arg("SN").c_str());
      if (server.hasArg("NL") && server.hasArg("NP"))
        settings.configUser(server.arg("NL").c_str(),
                            server.arg("NP").c_str());
      if (server.hasArg("OI"))
        settings.configIP(settings.stringToIP(server.arg("OI").c_str()),
                          settings.gatewayIP(),
                          settings.subnetMask());
      if (server.hasArg("OG"))
        settings.configIP(settings.localIP(),
                          settings.stringToIP(server.arg("OG").c_str()),
                          settings.subnetMask());
      if (server.hasArg("OM"))
        settings.configIP(settings.localIP(),
                          settings.gatewayIP(),
                          settings.stringToIP(server.arg("OM").c_str()));
      settings.save();
      CommonUtils::returnOK(&server, F("Settings saved"));
    } else if (server.arg("a") == "r") {
      CommonUtils::returnOK(&server, F("Settings reset. Rebooting..."));
      settings.remove(server.arg("SL").c_str(),
                      server.arg("SPL").c_str(),
                      SETTINGS_FILE);
      ESP.restart();
    } else CommonUtils::returnFail(&server, F("Method not allowed"));
  } else server.send(200, F("text/html"), settings_htm);
  return void();
}

void timeset() {
  if (!LoginPageHandler::verifyLogin(&server, &settings)) {
    LoginPageHandler::redirectToLogin(&server);
    return;
  }

  if (server.method() == HTTP_POST) {
    if (server.arg("a") == "l") {
      char _d[20];
      snprintf_P(_d, 20,
                 PSTR("%04u-%02u-%02uT%02u:%02u"),
                 teraz.Year(),
                 teraz.Month(),
                 teraz.Day(),
                 teraz.Hour(),
                 teraz.Minute());
      server.send(200, F("text/plain"), _d);
    } else if (settings.authenticate(
                 server.arg("SL").c_str(),
                 server.arg("SPL").c_str())) {
      if (server.arg("a") == "s") {
        if (server.hasArg("TZ"))
          settings.timezone = atoi(server.arg("TZ").c_str());
        if (server.hasArg("UN"))
          settings.useNTP = (server.arg("UN")[0] == '1');
        if (server.hasArg("NS"))
          settings.ntpServer(server.arg("NS").c_str());
        if (server.hasArg("EP")) {
          uint32_t newTime = strtoul(server.arg("EP").c_str(), NULL, 10);
          newTime += 3600 * settings.timezone;
          newTime -= 946684800;
          zegar.SetDateTime(RtcDateTime(newTime));
          settings.lastUpdate = newTime;
        }
        settings.save();
        returnOK(F("Time settings saved"));
      }
    } else CommonUtils::returnLoginFail(&server);
  }
  return void();
}

void returnOK(const __FlashStringHelper* _m) {
  server.send(200, F("text/plain"), _m);
  return void();
}

bool loadFromSdCard(String path) {
  if (digitalRead(SD_D))
    return false;
  String dataType = "text/plain";
  if (path.endsWith("/")) path += "index.htm";

  if (path.endsWith(".src")) path = path.substring(0, path.lastIndexOf("."));
  else if (path.endsWith(".htm")) dataType = "text/html";
  else if (path.endsWith(".csv")) dataType = "text/txt";

  File dataFile = SD.open(path.c_str(), FILE_READ);
  if (!dataFile)
    return false;

  if (server.streamFile(dataFile, dataType) != dataFile.size()) {
    Serial.println(F("Sent less data than expected!"));
  }

  dataFile.close();
  return true;
}

void handleNotFound() {
  if (!LoginPageHandler::verifyLogin(&server, &settings)) {
    LoginPageHandler::redirectToLogin(&server);
    return;
  }

  String p = server.uri();
  if (SD.exists("/data" + p) && !digitalRead(SD_D)) {
    handleIndex(p);
    return;
  }

  String message = F("PLIKU NIE ZNALEZIONO\n\n");
  message += F("URI: ");
  message += server.uri();
  message += F("\nMethod: ");
  message += (server.method() == HTTP_GET) ? F("GET") : F("POST");
  message += F("\nArguments: ");
  message += server.args();
  message += F("\n");
  for (uint8_t i = 0; i < server.args(); i++) {
    message += " NAME:" + server.argName(i) + "\n VALUE:" + server.arg(i) + "\n";
  }
  server.send(404, "text/plain", message);
}

void handleIndex(String path) {
  if (!LoginPageHandler::verifyLogin(&server, &settings)) {
    LoginPageHandler::redirectToLogin(&server);
    return;
  }

  File dir = SD.open("/data" + path, FILE_READ);
  if (!dir.isDirectory()) {
    dir.close();
    if (!digitalRead(SD_D) && loadFromSdCard("/data" + path)) return;
  }
  dir.rewindDirectory();

  server.setContentLength(CONTENT_LENGTH_UNKNOWN);
  server.sendContent(F("<!DOCTYPE html><html lang=\"en\">"));
  server.sendContent(F("<head><meta http-equiv=\"cache-control\" content"));
  server.sendContent(F("=\"no-cache\" /><title>Temperature Station"));
  server.sendContent(F("</title></head><body><a href=\"/logout\"><input type"));
  server.sendContent(F("=\"button\" value=\"Logout\" /></a><a href=\"/settings\">"));
  server.sendContent(F("<input type=\"button\" value=\"Settings\" /></a>"));
  server.sendContent(F("<a href=\"/sensors\"><input type=\"button\""));
  server.sendContent(F(" value=\"Sensors\" /></a><h1>Index of "));

  server.sendContent(path);
  server.sendContent(F("</h1><table><tr><th>Type</th><th>Name</th>"));
  server.sendContent(F("<th>Size</th></tr>"));

  server.sendContent(F("<tr><td>Dir</td><td><a href=\""));
  if (path.lastIndexOf('/') > 4)
    server.sendContent(path.substring(0, path.lastIndexOf('/')));
  else
    server.sendContent(F("/"));
  server.sendContent(F("\">..</a></td></tr>"));
  File entry;
  for (int cnt = 0; true; cnt++) {
    entry = dir.openNextFile();
    if (!entry) break;

    server.sendContent(F("<tr><td>"));
    server.sendContent(entry.isDirectory() ? F("Dir") : F("File"));
    server.sendContent(F("</td><td><a href=\""));
    server.sendContent(path);
    if (path != "/") server.sendContent("/");
    server.sendContent(String(entry.name()) + "\">");
    server.sendContent(entry.name());
    server.sendContent(F("</a></td><td>"));
    server.sendContent(String(entry.size()));
    server.sendContent(F("</td></tr>"));
  }
  entry.close();
  server.sendContent(F("</table></body></html>"));
  return void();
}

void createFile(char* _fn, uint8_t _buf, RtcDateTime& dt) {
  memset(_fn, 0, _buf);
  snprintf_P(_fn, _buf, PSTR("/data/%04u%02u"), dt.Year(), dt.Month());
  SD.mkdir(_fn);
  snprintf_P(_fn, _buf, PSTR("%s/%02u.csv"), _fn, dt.Day());
}

void I2C_clearBus() {
  //http://www.forward.com.au/pfod/ArduinoProgramming/I2C_ClearBus/index.html
  Serial.println(F("Resetting RTC I2C interface"));
  pinMode(SDA, INPUT_PULLUP);
  pinMode(SCL, INPUT_PULLUP);

  delay(2500);

  boolean SCL_LOW = (digitalRead(SCL) == LOW); // Check is SCL is Low.
  if (SCL_LOW)
    Serial.println("Cannot become master");

  boolean SDA_LOW = (digitalRead(SDA) == LOW);  // vi. Check SDA input.
  int clockCount = 20; // > 2x9 clock

  while (SDA_LOW && (clockCount > 0)) { //  vii. If SDA is Low,
    clockCount--;

    pinMode(SCL, INPUT);
    pinMode(SCL, OUTPUT);
    delayMicroseconds(10);
    pinMode(SCL, INPUT);
    pinMode(SCL, INPUT_PULLUP);
    delayMicroseconds(10); //  for >5uS
    // The >5uS is so that even the slowest I2C devices are handled.
    SCL_LOW = (digitalRead(SCL) == LOW); // Check if SCL is Low.
    int counter = 20;
    while (SCL_LOW && (counter > 0)) {  //  loop waiting for SCL to become High only wait 2sec.
      counter--;
      delay(100);
      SCL_LOW = (digitalRead(SCL) == LOW);
    }
    if (SCL_LOW) break;
    SDA_LOW = (digitalRead(SDA) == LOW); //   and check SDA input again and loop
  }
  if (SDA_LOW) { // still low
    Serial.println("SDA still low");
  }

  // else pull SDA line low for Start or Repeated Start
  pinMode(SDA, INPUT); // remove pullup.
  pinMode(SDA, OUTPUT);  // and then make it LOW i.e. send an I2C Start or Repeated start control.
  // When there is only one I2C master a Start or Repeat Start has the same function as a Stop and clears the bus.
  /// A Repeat Start is a Start occurring after a Start with no intervening Stop.
  delayMicroseconds(10); // wait >5uS
  pinMode(SDA, INPUT); // remove output low
  pinMode(SDA, INPUT_PULLUP); // and make SDA high i.e. send I2C STOP control.
  delayMicroseconds(10); // x. wait >5uS
  pinMode(SDA, INPUT); // and reset pins as tri-state inputs which is the default state on reset
  pinMode(SCL, INPUT);
  return void();
}

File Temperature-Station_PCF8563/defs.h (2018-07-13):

/*
  Mainboard_1.1
  #define SD_D D0 //GPIO16
  #define SDA D1 //GPIO5
  #define SCL D2 //GPIO4
  #define OW_PORT D3 //GPIO0
  #define SD_CS D4 //GPIO2
*/

#define SD_D A0
#define SDA 5
#define SCL 4
#define MUX_LOCK 2
#define SD_CS 16

//int isMember(byte, JsonArray&);
//int isMember(JsonArray&, JsonObject&);
//int isMember(int, JsonArray&);
int isMember(const uint8_t*, JsonArray&, uint8_t);
String addrToString(const uint8_t*, uint8_t);
//String addrToString(JsonArray&);

/*
   int isMember(byte _1[], JsonArray& compArr) {
  for (uint8_t a = 0; a < compArr.size(); a++) {
    for (uint8_t b = 0; b < 8; b++) {
      if (_1[b] != compArr[a][1][b].as<byte>())
        break;
      else if (b == 7) return a;
    }
  }
  return -1;
  }
*/

/*
  int isMember(JsonArray& locArr, JsonObject& remObj) {
  for (uint8_t locsiz = 0; locsiz < locArr.size(); locsiz++) {
    for (uint8_t a = 0; a < 8; a++) {
      if (locArr[locsiz][1][a].as<byte>() != remObj[1][a].as<byte>())
        break;
      else if (a == 7) return locsiz;
    }
  }
  return -1;
  }
*/

/*
  int isMember(int locAddr, JsonArray& remArr) {
  for (uint8_t remSiz = 0; remSiz < remArr.size(); remSiz++) {
    if (remArr[remSiz][1].is<int>() == false) continue;
    if (locAddr != remArr[remSiz][1].as<int>())
      continue;
    else return remSiz;
  }
  return -1;
  }
*/

int isMember(const uint8_t *_a, JsonArray& compArr, uint8_t _s) {
  for (uint8_t a = 0; a < compArr.size(); a++) {
    for (uint8_t b = 0; b < _s; b++) {
      if (*(_a + b) != compArr[a][1][b].as<uint8_t>())
        break;
      else if (b == 7) return a;
    }
  }
  return -1;
}

String addrToString(const uint8_t *_addr, uint8_t _s) {
  String out = "";
  for (uint8_t _a = 0; _a < _s; _a++)
    out += String(*(_addr + _a));
  return out;
}

/*
  String addrToString(JsonArray& _addr) {
  String out = "";
  for (uint8_t a = 0; (a < 8 && a < _addr.size()); a++)
    out += _addr[a].as<String>();
  return out;
  }
*/

void saveJson(JsonObject& toSave, const char* _f) {
  if (!toSave.success()) return;
  if (SD.exists(_f)) SD.remove(_f);
  File root = SD.open(_f, FILE_WRITE);
  toSave.printTo(root);
  root.flush();
  root.close();
  return void();
}

String printDateTime(Czas & timeobj) {
  char datestring[20];
  snprintf_P(datestring, 20,
             PSTR("%02u/%02u/%04u;%02u:%02u"),
             timeobj.day(),
             timeobj.month(),
             timeobj.year(),
             timeobj.hour(),
             timeobj.minute());
  return datestring;
}

void refreshSensors(Muxtemp* _s, const char* _n) {
  DynamicJsonBuffer jsonBuffer(2250);
  File root;
  if (!SD.exists(_n)) {
    Serial.println("no file yo");
    root = SD.open(_n, FILE_WRITE);
    root.print(F("{\"remote\":[],\"local\":[],\"saved\":[]}"));
    root.flush();
    root.close();
  }

  root = SD.open(_n);
  JsonObject& nSet = jsonBuffer.parseObject(root);
  root.close();

  JsonArray& _l = nSet["local"];
  JsonArray & _saved = nSet["saved"];

  bool _ch = false;
  int8_t dif = _s->getCount() - _l.size();
  if (dif > 0) {
    for (uint8_t z = 0; z < dif; z++) {
      JsonArray& _e = _l.createNestedArray();
      _e.add("Port_" + String(_l.size()));
      _e.add(false);
    }
    _ch = true;
  }

  _s->getPorts();
  for (int a = 0; a < _s->getCount(); a++) {
    JsonArray& _curr =  _l[a];
    uint8_t _type = _s->typeOf(a);
    switch (_type) {
      case 0: _curr[1] = false;
        _ch = true;
        break;
      case 11:
      case 21:
      case 22:
        _curr[1] = true;
        _ch = true;
        break;
      case 40:
        uint8_t *_q = _s->getAddress(a);
        int pos = isMember(_q, _saved, 8);
        if (pos == -1 && *_q == 40) {
          JsonArray& _new = _saved.createNestedArray();
          String _a = addrToString(_q, 8);
          _new.add(_a);
          JsonArray& _ad = _new.createNestedArray();
          for (uint8_t y = 0; y < 8; y++) _ad.add(*(_q + y));
          a--;
          break;
        } else _curr[1] = pos;
        delete _q;
        _ch = true;
        break;
    }
  }
  if (_ch) saveJson(nSet, _n);
  return;
}

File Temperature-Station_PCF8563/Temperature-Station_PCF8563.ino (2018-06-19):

#include <ArduinoJson.h> //github: bblanchon
#include <Czas.h> //PCF8563 library
#include <ESP8266HTTPUpdateServer.h>
//#include <ESP8266WebServer.h>
#include <ESP8266WebServerSecure.h>
#include <ESP8266WiFi.h>
#include <Muxtemp.h>
#include <Pinger.h> //Alessio Leoncini
#include <SD.h>
#include <SPI.h>
#include <WiFiClient.h>
#include <WiFiUdp.h>
#include "settingsHandler.h"
#include "html_set.h"

#define FS_NO_GLOBALS
#define DEFAULT_TIMEOUT 1000
#include "FS.h"
#include "defs.h"

/*
  curl -F "image=@Temperature-Station_PCF8563.ino.nodemcu.bin" -u admin:admin 192.168.2.98/update

  Pinger 1.0.0
  LwIP v2 Higher Bandwidth
  You need to generate x509 key using script somewhere in ESP examples
  When setting time - use GMT+0 time without DST  (DST will be automatic)

  ToDO:
    Remake /sensors button to sync 1wire with all devices
    Select if 1wire can override port name
    Select if master can overwrite slave settings
    Add backup options
    Automatic DST
    Secure connection with slave but dosen't need to be
    Move index to be hard-coded
    SET: require authentication, confirm password to change it or username
    Finish backend
    Encrypt passwords
*/
#define MAX_SENSORS 16

bool httpserver = false;
bool letni = true;
uint8_t ports = 0;
uint32_t nextAvailable = 0; //Solve this in Muxtemp only when scanning ports!
const uint32_t minDelay = 10000;

ESP8266WebServer server(80);
WiFiUDP udp;
//ESP8266WebServerSecure server(443);
ESP8266HTTPUpdateServer updServer;

WiFiClient telnet;
WiFiClient debugClient;
WiFiServer debugServer(23);

Czas zegar(Wire);
Muxtemp ext(Wire);
settingsHandler settings;

void setup() {
  pinMode(SD_D, INPUT);
  pinMode(0, OUTPUT);
  digitalWrite(2, LOW);

  //For testing purposes
  //ESP.eraseConfig();
  //SPIFFS.format();

  delay(1000);
  Wire.begin(SDA, SCL);
  Serial.begin(115200);
  Serial.println(F("Temperature Station"));
  Serial.setDebugOutput(false);
  WiFi.persistent(false);

  ///////////////////////////////
  IPAddress ip(192, 168, 2, 98);
  IPAddress gateway(192, 168, 2, 1);
  IPAddress subnet(255, 255, 255, 0);
  settings.configAP("TemperatureStation", "TemperatureStation");
  settings.useDHCP(false);
  settings.name("TemperatureStation");
  settings.configIP(ip, gateway, subnet);
  settings.ntpServer("tempus1.gum.gov.pl");
  settings.configUser("admin", "admin");
  settings.timezone = 1;
  settings.useNTP = true;
  Serial.println("Saving");
  settings.save("/set.txt");
  ///////////////////////////////

  Serial.print(F("Loading... "));
  settings.serialDebug(&Serial);
  if (!settings.load("/set.txt")) { //Defaults
    Serial.println(F("Fail"));
    settings.configUser("admin", "admin");
    settings.name("TemperatureStation");
    settings.configAP(("TemperatureStation" + (String)ESP.getChipId()).c_str(), "TemperatureStation");
  } else Serial.println(F("OK"));

  bool gotwifi = false;
  if (strcmp(settings.ssid(), "") != 0) {
    Serial.print(F("Connecting to:\r\n\t\t"));
    Serial.print(settings.ssid());
    Serial.print(F("... "));
    if (settings.beginWiFi()) {
      Serial.print(F("Success ("));
      Serial.print(WiFi.localIP());
      Serial.println(F(")"));
      gotwifi = true;
    } else {
      Serial.println(F("Connection failed"));
      gotwifi = false;
    }
  }
  if (!gotwifi) {
    Serial.println(F("Starting Access Point..."));
    settings.beginAP();
    Serial.print(F("Connect to:\t"));
    Serial.println(settings.ssidAP());
  }
  Serial.print(F("\r\nMuxtemp:\t"));
  Serial.println((ext.begin(0x10) == 0) ? F("Present") : F("Error"));
  Serial.print(F("Ports:  \t"));
  Serial.println(ext.getCount());
  Serial.print(F("1wire bypass:\t"));
  Serial.println(ext.bypass1Wire() ? F("yes") : F("no"));
  Serial.println();
  ext.refreshPorts();
  nextAvailable = millis() + minDelay;

  if (analogRead(SD_D) < 512) {
    if (SD.begin(SD_CS)) {
      Serial.println(F("SD Card initialized"));
      if (!SD.exists("/SENSORS.TXT"))
        Serial.println(F("No sensors file!"));
    } else Serial.println(F("SD Card detected but cannot be initialized!"));
  } else Serial.print(F("No card inserted\n"));

  settings.configUpdateServer(&server, &updServer, "/update");
  //server.setServerKeyAndCert_P(rsakey, sizeof(rsakey), x509, sizeof(x509));
  server.on("/settings", devconfig);
  server.on("/sensors", sensorSettings);
  server.on("/sensorsbdc", sensorBroadcast);
  server.on("/time", HTTP_POST, timeset);
  server.on("/list", HTTP_GET, printDirectory);
  server.on("/sysinfo", HTTP_GET, httpinfo);
  server.on("/", HTTP_DELETE, handleDelete);
  server.on("/", HTTP_PUT, handleCreate);
  server.on("/", HTTP_POST, []() {
    returnOK();
  }, handleFileUpload);
  server.onNotFound(handleNotFound);
  server.begin();
  Serial.println(F("HTTP server:\tStarted"));
  debugServer.begin();
  //This has no sense
  //But still it looks good while booting :)

  //Emergency connection - update or something
  //In case when dosen't detect SDcard, wrong config etc

  udp.begin(2390);
  zegar.readRTC();
  if (settings.useNTP && gotwifi) {
    Serial.print(F("NTP server:\t"));
    Serial.println(settings.ntpServer());
    uint32_t newTime = updateNTP(settings.ntpServer());
    Serial.print(F("NTP Time:\t"));
    Serial.println(newTime);
    Serial.print(F("Current Time:\t"));
    Serial.println(zegar.dateAsEpoch());
    if (newTime != 0 && ((newTime - zegar.dateAsEpoch()) > 59)) {
      Serial.println(F("Adjusting time..."));
      zegar.setRTC(newTime);
      delay(10);
      zegar.readRTC();
      settings.lastUpdate = newTime;
    }
    settings.save("/set.txt");
  }
  if (zegar.dateAsEpoch() < 59) zegar.setRTC(settings.lastUpdate);
  Serial.println(printDateTime(zegar));

  while (millis() < (nextAvailable - 5000))
    server.handleClient();

  refreshSensors(&ext, "/SENSORS.TXT");
  nextAvailable = millis() + minDelay;

  DynamicJsonBuffer jsonBuffer(2250);
  File root = SD.open("/SENSORS.TXT", FILE_READ);
  JsonObject& nSet = jsonBuffer.parseObject(root);
  root.close();

  JsonArray& _saved = nSet["saved"];
  Serial.println(F("\r\nLocal:"));
  for (int a = 0; a < ext.getCount(); a++) {
    uint8_t _type = ext.typeOf(a);
    JsonObject& _curr = nSet["local"][a];

    Serial.print('\t' + (String)(a + 1) + "/" + (String)(ext.getCount()) + ": ");
    Serial.print('\t' + String(ext.typeOf(a)) + '\t');
    if (_type == 0) Serial.print(F("N/C"));
    else if (_type != 5) {
      Serial.println(_curr["n"].as<const char*>());
      continue;
    } else if (_type == 5) {
      uint8_t *_q = ext.getAddress(a);
      int pos = isMember(_q, _saved, 8);
      Serial.print(_saved[pos]["n"].as<const char*>());
      Serial.print(F("\t("));

      for (uint8_t y = 0; y < 8; y++) {
        Serial.print(*(_q + y));
        if (y < 7) Serial.print(",");
        else Serial.print(')');
      }
    }
    Serial.println();
  }
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

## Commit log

2017-06-02 Initial commit
    Lots of things done, more to do.
    Works fine unless you want to use advanced options.
    Documentation planned in the future.
    [Mainboard_1.1.kicad_pcb, Mainboard_1.1.sch, Temperature-Station.fzz]
2017-06-03 Fixes
    Added static/dhcp option for obtaining IP address
    Little changes to code
    [Mainboard_1.1.kicad_pcb, Mainboard_1.1.sch]
2017-06-06 Fixes
    Fixed editing, saving and uploading documents to server
    Minor code changes
    Minor board changes
    [Mainboard_1.1.kicad_pcb]
2017-06-17 Mainboard changes
    [Mainboard_1.1.kicad_pcb, Mainboard_1.1.sch]
2017-06-18 templates
    Fixed template
    TODO: get temperature from device using table row number (order defined
    in template.txt)
2017-06-19 Things got better
    Added templates
    Improved method of logging
    Minor changes in board
    [Mainboard_1.1.kicad_pcb]
2017-06-20 Some things fixed
    Removed test sketches
    Working on JSON as config
    Some bugs fixed
    Modified IPconfig sketch to take ssid and pass from compiled sketch, not
    file on SDcard so it's easier to use.
    [Temperature-Station_PCF8563_JSON.ino, defs.h]
2017-06-21 JSON support added
    Now PCF8563 version is working with JSON configs. Less files, but
    responsibility is great.
    Works well as far, but the goal is removing vars containing addresses,
    sensor names and reading JSON directly from SDcard.
2017-06-26 Fixes
    Fixed opening files from archive file tree
    Idk HOW IT WAS CREATING NEW FILES before. Now everything is 100% legit.
    Still many things to do.
    [Temperature-Station_PCF8563_JSON.ino]
2017-06-27 Application, configuration
    See changes in README
    Added program to create settings.txt
    Added GET url (/sensors) to list all connected sensors (WIP)
    I forgot what else.
2017-07-01 Fixes and additions
    Splitted README files
    Modified SettingsGenerator
    Added "backup access points" feature on boot
    Fixed midnight bug
    [Mainboard1.1_LF33CDT.kicad_pcb, Mainboard1.1_LF33CDT.sch, Mainboard1.1_LM1117.kicad_pcb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]
2017-07-03 SettingsGenerator update
    Added validating addresses in SettingsGenerator
    Modified LM1117 board (SOT instead of DPAK voltage stabiliser)
    Something I forgot
    [Mainboard1.1_LM1117.kicad_pcb, Mainboard1.1_LM1117.sch]
2017-07-08 PCB work
    Started working on full SMD version. Update KiCAD library before opening
    this one.
    Modified code and moved clock settings to JSON (needs update!) - I must
    upload new JSON and SettingsGenerator.
    Set all strings to flash memory
    [Mainboard2.0_LM1117.kicad_pcb, Mainboard2.0_LM1117.sch]
2017-07-09 PCB work
    Need to remove 1.1 files from 2.0 folder
    Fixed component enumeration so PCB rework will be easier
    Still need to finish new PCB
    [Mainboard1.1_LM1117.sch, Mainboard2.0_LM1117.kicad_pcb, Mainboard2.0_LM1117.sch]
2017-07-15 Minor code changes
    Little cleanup
    Cosmetic changes
    Added keywords for Czas.h library and moved to it's own directory (otherwise keywords won't work)
    Removed unnescesary crap I forgot to remove earlier
    Updated description in README for PCF8563_JSON
    Updated SettingsGenerator for newest JSON
    Had a little fun with new PCB but I don't think it's gonna work out
    [Mainboard2.0_LM1117.kicad_pcb]
2017-07-16 Updates
    Added new IP obtain mode
    Changed PC program name
    Fixed compilator warnings
    Removed support for DHCP.txt file
    Czas.h: added function to compare given epoch to current date and time
    [Czas.cpp, Temperature-Station_PCF8563_JSON.ino, defs.h]
2017-07-25 SMD board complete
    Full SMD board is complete - needs to be tested though. Looks kinda awful, large SD card slot is taking lots of space.
    [Mainboard1.1_LM1117.sch, Mainboard2.0_LM1117.kicad_pcb, Mainboard2.0_LM1117.sch]
2017-09-20 Updates
    Ported DS3231 to JSON
    [Mainboard2.0_LM1117.kicad_pcb, Mainboard2.0_LM1117.sch]
2017-10-02 DS3231 update
    Change sensor names through /sensors
2017-10-04 DS3231 update
    Auto adding sensors
    Can remove unplugged sensors
    Auto-add freshly connected
    TODO:
    Fix removing sensors
    [defs.h]
2017-10-05 PCF8563&DS3231 Update
    Both versions have the same features (and bugs)
    Reworked NTP time setting
    Fixed sensor removing (kind of)
    Slight memory optimization
    Automatic redirection after sensor manipulation
    Moved everything I could to FLASH instead of RAM memory.
    [Temperature-Station_PCF8563_JSON.ino, defs.h]
2017-11-02 Updates
    Updated both versions
    Added online updater
    Minor cosmetic changes
    Saving DHCP settings restored
    Added authentication (still no HTTPS/TLS/SSL tho)
    Moved as many Strings as possible to Flash memory to free RAM
    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
    [Mainboard1.1_LM1117.kicad_pcb, Mainboard1.1_LM1117.sch, Mainboard2.0_LM1117.kicad_pcb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]
2018-01-23 Updates
    Reduced size of variables
    Settings file protected by code (not shown in site)
    Added button for sensor settings
    Files read only (webpage)
    Changed log file format (dynamic sensors friendly)
    Fixed bug where watchdog resets mcu when entering password
    [Temperature-Station_PCF8563_JSON.ino, defs.h]
2018-02-22 Update
    Czas:
    Convert date to epoch (1-1-2000)
    Station:
    Config file in SPIFFS
    Web configuration
    Sensors file on SDcard
    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
2018-04-23 Large updates
    SSL website (need to generate your own key.h and x509.h using script in ESP examples)
    Online config (without time settings yet)
    New board (3.0)
    WIP sensor settings (/sensors, removing temporarily disabled)
    Added slave devices (need low level configuration at the moment)
    Working on self-AP when there is no WiFi connection
    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
    [Mainboard1.1_LF33CDT.kicad_pcb, Mainboard1.1_LF33CDT.sch, Mainboard1.1_LM1117.sch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]
2018-05-08 Little update
    Slave device can be configured (WIP)
    Working on expansion board (WIP)
2018-05-11 Updates
    Added slave board with library (Muxtemp) - DHT11/21/22 sensors
2018-05-23 Added external boards
    Added RJ45 breakout board which will need specifically prepared cable
    Added RJ45 independent I2C extension board (WIP)
    Documentation coming soon
    [RJ45_Breakout.kicad_pcb, RJ45_Breakout.sch, RJ45_I2C_1.0.kicad_pcb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]
2018-05-27 Updated boards and sketches
    Boards:
    Sandwich-like layout so you can connect directly do DHT sensors or use i2c expansion (8 slots).
    Boards support 1wire, DHT11/21/22 sensors and require custom wiring.
    Reduced size of boards
    Sketch:
    Hermetized settings (no way to read passwords)
    Used settingsHandler to hold every field that will have to be saved
    Fixed AP launch in PCF8563
    Rolled back Pinger library due to readability issues.
    WIP: Use external memory only for emergency sensor file and permanently for readings
    TESTING: Update via curl
    TESTING: Set time and date via webpage
    WIP: Change settings via webpage
    WIP: Change login credentials via webpage
    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
    [RJ45_Breakout.kicad_pcb, RJ45_I2C_1.0.kicad_pcb, RJ45_I2C_1.0.sch]
2018-06-01 Muxtemp update
    Fixed begin()
    Removed function that only read ports (now it will only probe&read)
    Fixed typo (requesting fixed number of devices even if real amount is different)
    TODO: 1wire connection
    [RJ45_Breakout.kicad_pcb]
2018-06-03 Muxtemp update
    1wire option added
    Working in bypass or local mode (if master can use 1wire it will NOT use 1wire devices)
    Example shows more info
    [RJ45_I2C_1.0.kicad_pcb, RJ45_I2C_1.0.sch]
2018-06-10 Large update
    Muxtemp:
    Optimized timing
    Added library.properies
    No compiler warnings
    No compiler warnings
    I2C Expander:
    Minor optimization
    Added 1wire bypass (will require jumpers)
    Added debug mode
    No idea why but DHT22 is detected as DHT21
    Improved stability
    PCF8563 version:
    Defaults are in sketch, not settingsHandler library
    Fixed sensor view (renaming, deleting etc)
    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
    [Mainboard_3.0.sch]
2018-06-19 Update
    Halfway through
    Preparing to make very dumb version (different branch)
    [Slave_PCB.kicad_pcb, Slave_PCB.sch]
2018-07-08 Small updates
    Czas: added option to validate dat/time
    Muxtemp: added software lock placed by refresh() due to slow DHT sensors (going to be changed in next I2C breakout)
    More changes coming soon
2018-07-09 Cleaned boards up
    Merged RJ45_I2C with RJ45_Breakout into one schematic
    Added fully-integrated Muxtemp board
    Started working on Mainboard+Muxtemp board
    Settings page (html) is now functional. Backend WIP.
    SettingsHandler(PCF8563) is now cleaned up a bit, added optional define to include debug interface
    Added option to configure OTA updater as well as WebUpdater
    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
    [Mainboard_Final.sch, Muxtemp.kicad_pcb, Muxtemp.sch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]
2018-07-13 Optimizations and updates
    PCF8563:
    Added non-address version (sensor dosen't override port name)
    Finished settings
    Index and settings are stored in sketch, not SD-card
    Minor optimization (migrate to const char* instead of string)
    Temporarily disabled remote devices
    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
    [Mainboard_1.1.kicad_pcb, Mainboard_1.1.sch, Mainboard_2.0.kicad_pcb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]
2019-04-30 Updates
    Library controls lock line entirely
    Temperature-Station DS3231:
    Prepared to use HTTPS
    Moved config to SPIFFS
    Moved webpages to SPIFFS
    RTC is now adjusted if the difference is over 1 minute (on reboot)
    Removed daylight saving entirely (I think)
    Adjustable reading interval
    Added authentication on every request
    Shorter names for variables on webpage
    Changed index to Mozilla FTP-like layout
    Added handler for changing time/date
    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
    [Temperature-Station_DS3231.ino, defs.h]
2019-05-11 Backend rebuild
    Changing structure of webserver
    Added cookie based authentication
    Moved from HTTPUpdater to ArduinoOTA
    Added CommonUtils to let backend interact with main loop
